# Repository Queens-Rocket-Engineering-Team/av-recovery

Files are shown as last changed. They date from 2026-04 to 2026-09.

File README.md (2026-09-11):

# Avionics Recovery (GPS and Altimter)
> 2023-2026 Season - Recovery Projects

> [!IMPORTANT]
> Make sure to initialize and pull the repository's git submodules to acquire all schematic library and board design dependencies:
> ```bash
> git submodule update --init --recursive
> ```

-  Repo contains board's **firmware**, **schematics**, and related **documentation and datasheets**.
-  The **Main** branch contains current functional hardware/software
-  **Branches** contain board revisions/versions or planned features/fixes.
-  If you're contributing, **make sure you're working in a branch other than Main**

### Folder Structure
- [`/Schematics`](./Schematics/) : PCB design files (KiCad V8)  
- [`/Firmware`](./Firmware/) : Arduino C/C++ code (for STM)
- [`/Datasheets`](./Datasheets/) : Datasheets and reference materials

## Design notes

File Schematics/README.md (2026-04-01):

# Schematics

This directory contains all schematics involved in this iteration of the Avionics Recovery system.

## GPS Module
- Acquires GPS signal
- Logs GPS data locally

## Altimter Module
- Tracks altitude using pressure and accelerometer
- Deploys parachute charges
- Logs altitude, pressure, events, etc. locally

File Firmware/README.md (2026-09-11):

# Recovery Module Firmware

This directory contains the firmware for the avionics Recovery Modules. The module firmware in this directory should be mostly functional.

We currently use the Arduino IDE with the STM32Duino core ("STM32 MCU based boards" by STMicroelectronics, working with 2.7.1) for developing firmware for our modules. We flash firmware to the modules using SWD via an STLinkV2.

## Attributions

Our firmware uses a variety of external libraries. Most libraries can be found through the Arduino library manager, and those that cannot have the corresponding GitHub link beside their include statements. We have taken care not to include any external libraries within our repository; only code we have written (or have modified and credited) are included here.

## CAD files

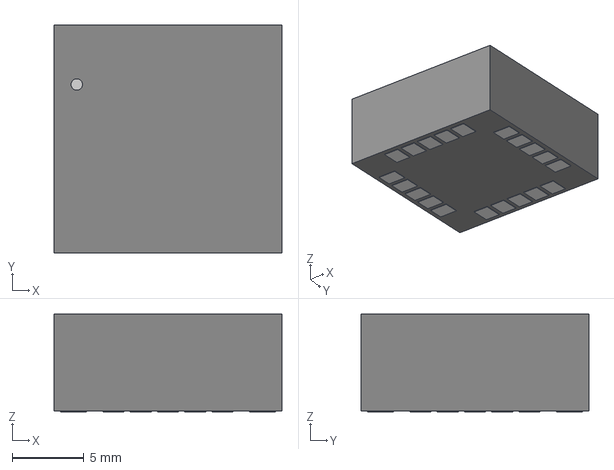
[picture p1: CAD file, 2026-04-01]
Schematics/GPS_Antenna_Board/models/SAM-M10Q_UBL.step
15.9 x 15.9 x 6.81 mm

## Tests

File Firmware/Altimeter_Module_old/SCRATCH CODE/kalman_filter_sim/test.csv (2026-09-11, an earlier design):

Time | Actual Altitude | Measured Altitude | Estimated Altitude | Actual Velocity | Estimated Velocity
0 | 0.0045 | -0.1955 | -0.101693 | 0.3 | 0.195812
0.01 | 0.012 | 0.212 | 0.0209463 | 0.6 | 0.614993
0.02 | 0.0225 | -0.1775 | -0.0386365 | 0.9 | 0.84776
0.03 | 0.036 | 0.136 | 0.0205453 | 1.2 | 1.19597
0.04 | 0.0525 | 0.4525 | 0.153328 | 1.5 | 1.61529
0.05 | 0.072 | -0.228 | 0.0600471 | 1.8 | 1.80436
0.06 | 0.0945 | -0.4055 | -0.0534859 | 2.1 | 1.97128
0.07 | 0.12 | -0.08 | -0.0452763 | 2.4 | 2.25728
0.08 | 0.1485 | -0.3515 | -0.110828 | 2.7 | 2.46666
0.09 | 0.18 | -0.12 | -0.0942345 | 3 | 2.7561
0.1 | 0.2145 | -0.1855 | -0.0977243 | 3.3 | 3.02255
0.11 | 0.252 | 0.452 | 0.074034 | 3.6 | 3.46258
0.12 | 0.2925 | -0.00750001 | 0.0783585 | 3.9 | 3.72979
0.13 | 0.336 | 0.036 | 0.0952273 | 4.2 | 4.00786
0.14 | 0.3825 | 0.5825 | 0.257225 | 4.5 | 4.42828
0.15 | 0.432 | 0.832 | 0.445922 | 4.8 | 4.8702
0.16 | 0.4845 | 0.1845 | 0.411931 | 5.1 | 5.08501
0.17 | 0.54 | 0.94 | 0.592801 | 5.4 | 5.51353
0.18 | 0.5985 | 0.3985 | 0.58164 | 5.7 | 5.74474
0.19 | 0.66 | 0.26 | 0.537766 | 6 | 5.94092
0.2 | 0.7245 | 1.1245 | 0.74073 | 6.3 | 6.38298
0.21 | 0.792 | 0.392 | 0.694199 | 6.6 | 6.57112
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

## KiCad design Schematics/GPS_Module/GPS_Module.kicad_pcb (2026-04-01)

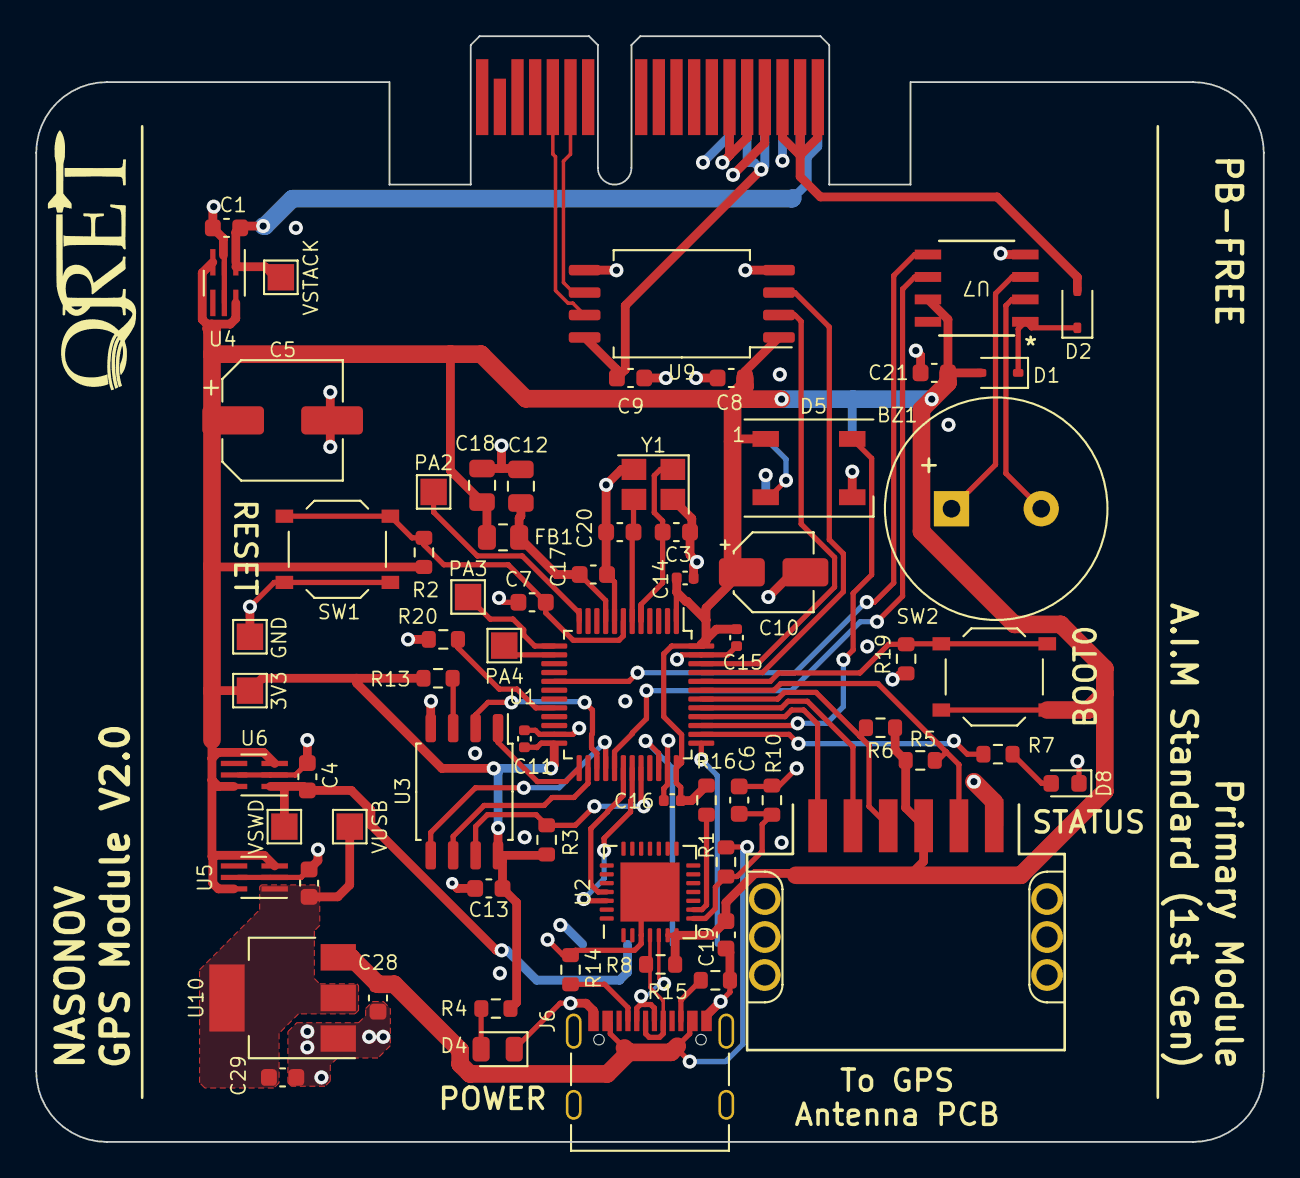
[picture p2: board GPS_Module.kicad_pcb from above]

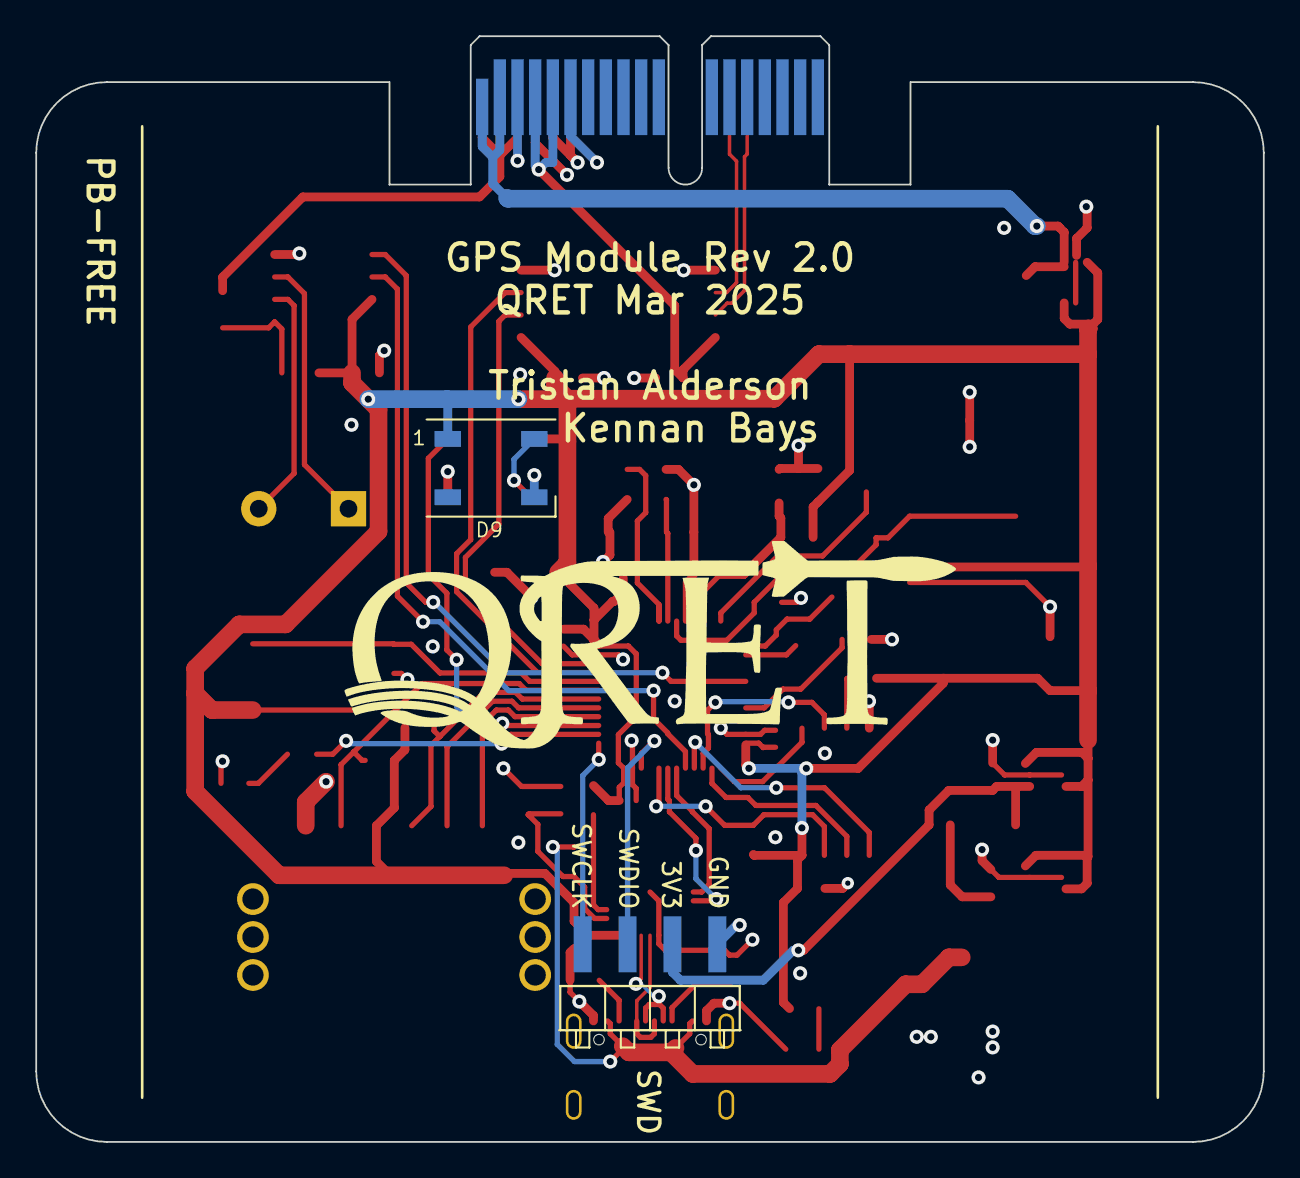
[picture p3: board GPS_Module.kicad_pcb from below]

Board: 4 copper layers, 69.5 x 62.6 mm, 70 parts (2 on the bottom side), 51 nets.

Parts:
BZ1: PS1240P02BT; Buzzer_12.6x9.5RM5.0
C1, C2, C4, C6: 1uF; C_0603_1608Metric
C3, C20: 10p; C_0603_1608Metric
C5: 100uF; CP_Elec_6.3x5.9
C7, C13, C21: 100nF; C_0603_1608Metric
C8, C9: 0.1u; C_0603_1608Metric
C10: 10uF; CP_Elec_4x5.4
C11, C14, C15, C16: 100n; C_0402_1005Metric
C12, C18: 1uF; C_0805_2012Metric
C17: 10n; C_0603_1608Metric
C19, C28, C29: 10uF; C_0603_1608Metric
D1, D2: 1N5819WS; D_SOD-323
D4: PWR_LED (GRN); LED_0805_2012Metric
D5, D9: WS2812B; LED_WS2812B_PLCC4_5.0x5.0mm_P3.2mm
D8: DB_LED (YLW); LED_0603_1608Metric
FB1: 100R; R_0805_2012Metric
J1: GT8E-6P-2H(55); CONN_GT8E-6P-2H(55)
J2: SWD_01x04_Pin; SWD_PinHeader_1x04_P2.54mm_Horizontal_SMD
J4: Stack Male Edge Connector; BUS_PCIexpress_x1
J6: USB_C_Female_USB2_Small; USB_C_DB-108PWB
R1: 22k; R_0603_1608Metric
R2, R3, R13: 10k; R_0603_1608Metric
R4: 3.3k; R_0603_1608Metric
R5, R6: 2.2k; R_0603_1608Metric
R7: 680; R_0603_1608Metric
R8: 1.5k; R_0603_1608Metric
R10: 47k; R_0603_1608Metric
R14, R15: 5.1k; R_0603_1608Metric
R16: 1k; R_0603_1608Metric
R19, R20: 100k; R_0603_1608Metric
SW1: SW_STM_RESET; SW_Push_1P1T_XKB_TS-1187A
SW2: SW_STM_BOOT_MODE; SW_Push_1P1T_XKB_TS-1187A
TP1: VSTACK; TestPoint_Pad_1.5x1.5mm
TP2: VUSB; TestPoint_Pad_1.5x1.5mm
TP3: VSWD; TestPoint_Pad_1.5x1.5mm
TP4: PA4; TestPoint_Pad_1.5x1.5mm
TP6: GND; TestPoint_Pad_1.5x1.5mm
TP7: 3V3; TestPoint_Pad_1.5x1.5mm
TP10: PA2; TestPoint_Pad_1.5x1.5mm
TP11: PA3; TestPoint_Pad_1.5x1.5mm
U1: STM32F103CBT6; LQFP-48_7x7mm_P0.5mm
U2: CP2102N-Axx-xQFN28; QFN-28-1EP_5x5mm_P0.5mm_EP3.35x3.35mm
U3: W25Q128JVS; SOIC-8_5.23x5.23mm_P1.27mm
U4, U5, U6: LM66100DCKR; SC-70-6_Handsoldering
U7: TPM8837C-SO1R; SOP-8_TPK
U9: ISO1042BQDWVR; SOIC-8 ISO1042BDWV
U10: AMS1117-3.3; SOT-223-3_TabPin2
Y1: X322516MMB4SI; Crystal_SMD_3225-4Pin_3.2x2.5mm

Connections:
5V_RAW: C28.1, J6.A4 (VBUS), J6.A9 (VBUS), J6.B4 (VBUS), J6.B9 (VBUS), R1.2, U10.3 (VI)
+3.3V: C5.1, C8.2, C10.1, C11.1, C13.1, C14.1, C15.1, C16.1, C18.1, C19.2, C21.1, D1.2 (A), D5.1 (VDD), D9.1 (VDD), FB1.2, J1.3, R2.2, R3.2, R4.2, R5.2, R6.1, R8.1, R13.2, R16.2, SW2.2, TP7.1, U1.1 (VBAT), U1.24 (VDD), U1.36 (VDD), U1.48 (VDD), U2.6 (VDD), U2.7 (VREGIN), U3.8 (VCC), U4.3 (*CE), U4.6 (VOUT), U5.3 (*CE), U5.6 (VOUT), U6.3 (*CE), U6.6 (VOUT), U7.7 (NSLEEP), U7.8 (VCC), U9.1 (VCC1)
+3.3VA: C12.1, C17.1, FB1.1, U1.9 (VDDA)
+5V: C9.2, J4.A4 (5.0V_A), J4.A5 (5.0V_A), U9.8 (VCC2)
+BATT: D2.2 (A), J4.B1 (BATT_A), J4.B2 (BATT_A), J4.B3 (BATT_A)
BOOT0: R19.2, SW2.1, U1.44 (BOOT0)
BOOT1: R20.2, U1.20 (PB2)
BUZZER_A: U1.29 (PA8), U7.6 (IN1)
BUZZER_B: U1.17 (PA7), U7.5 (IN2)
CAN_H: J4.B14 (CAN_H), U9.7 (CANH)
CAN_L: J4.B13 (CAN_L), U9.6 (CANL)
CAN_RX: U1.45 (PB8), U9.3 (RXD)
CAN_TX: U1.46 (PB9), U9.2 (TXD)
CS_FL: U1.25 (PB12), U3.1 (~CS)
DB_LED: R7.2, U1.38 (PA15)
EXTINT_GPS: J1.5, U1.41 (PB5)
GND: C1.2, C2.2, C3.2, C4.2, C5.2, C6.1, C7.2, C8.1, C9.1, C10.2, C11.2, C12.2, C13.2, C14.2, C15.2, C16.2, C17.2, C18.2, C19.1, C20.2, C21.2, C28.2, C29.2, D4.1 (K), D5.3 (VSS), D8.1 (K), D9.3 (VSS), J1.1, J2.1 (GND), J4.A3 (GND_A), J4.A6 (GND_A), J4.B4 (GND_A), J4.B5 (GND_A), J4.B6 (GND_A), J6.A1 (GND), J6.A12 (GND), J6.B1 (GND), J6.B12 (GND), R10.1, R14.2, R15.2, R19.1, R20.1, SW1.1, TP6.1, U1.8 (VSSA), U1.23 (VSS), U1.35 (VSS), U1.47 (VSS), U2.3 (GND), U2.29 (GND), U3.4 (GND), U4.2 (GND), U4.5 (ST), U5.2 (GND), U5.5 (ST), U6.2 (GND), U6.5 (ST), U7.4 (GND), U9.4 (GND1), U9.5 (GND2), U10.1 (GND), Y1.2, Y1.4
MISO_FL: U1.27 (PB14), U3.2 (DO(IO1))
MOSI_FL: U1.28 (PB15), U3.5 (DI(IO0))
unnamed: BZ1.2 (+), U7.2 (OUT1)
unnamed: BZ1.1 (-), U7.3 (OUT2)
unnamed: D1.1 (K), D2.1 (K), U7.1 (VM)
unnamed: D4.2 (A), R4.1
unnamed: D5.2 (DOUT), D9.4 (DIN)
unnamed: D8.2 (A), R7.1
unnamed: J6.A5 (CC1), R14.1
unnamed: J6.B5 (CC2), R15.1
unnamed: TP10.1, U1.12 (PA2)
unnamed: TP11.1, U1.13 (PA3)
unnamed: TP4.1, U1.14 (PA4)
unnamed: C6.2, R1.1, R10.2, U2.8 (VBUS)
unnamed: R16.1, U2.9 (~RST)
unnamed: R13.1, U3.3 (IO2)
OSC_IN: C3.1, U1.5 (PD0), Y1.1
OSC_OUT: C20.1, U1.6 (PD1), Y1.3
RESET_FL: R3.1, U1.32 (PA11), U3.7 (IO3)
RGB_DATA: D5.4 (DIN), U1.39 (PB3)
RST_GPS: J1.6, U1.40 (PB4)
SCK_FL: U1.26 (PB13), U3.6 (CLK)
SCL_GPS: J1.4, R6.2, U1.42 (PB6)
SDA_GPS: J1.2, R5.1, U1.43 (PB7)
STM_RESET: C7.1, R2.1, SW1.2, U1.7 (NRST)
SWCLK: J2.4 (SWCLK), U1.37 (PA14)
SWDIO: J2.3 (SWDIO), U1.34 (PA13)
USB_D+: J6.A6 (D+), J6.B6 (D+), R8.2, U2.4 (D+)
USB_D-: J6.A7 (D-), J6.B7 (D-), U2.5 (D-)
USB_RX: U1.31 (PA10), U2.26 (TXD)
USB_TX: U1.30 (PA9), U2.25 (RXD)
V_PSU: C1.1, J4.A1 (3.3V_A), J4.A2 (3.3V_A), TP1.1, U4.1 (VIN)
V_REGUSB: C2.1, C29.1, TP2.1, U5.1 (VIN), U10.2 (VO)
V_SWD: C4.1, J2.2 (3V3), TP3.1, U6.1 (VIN)

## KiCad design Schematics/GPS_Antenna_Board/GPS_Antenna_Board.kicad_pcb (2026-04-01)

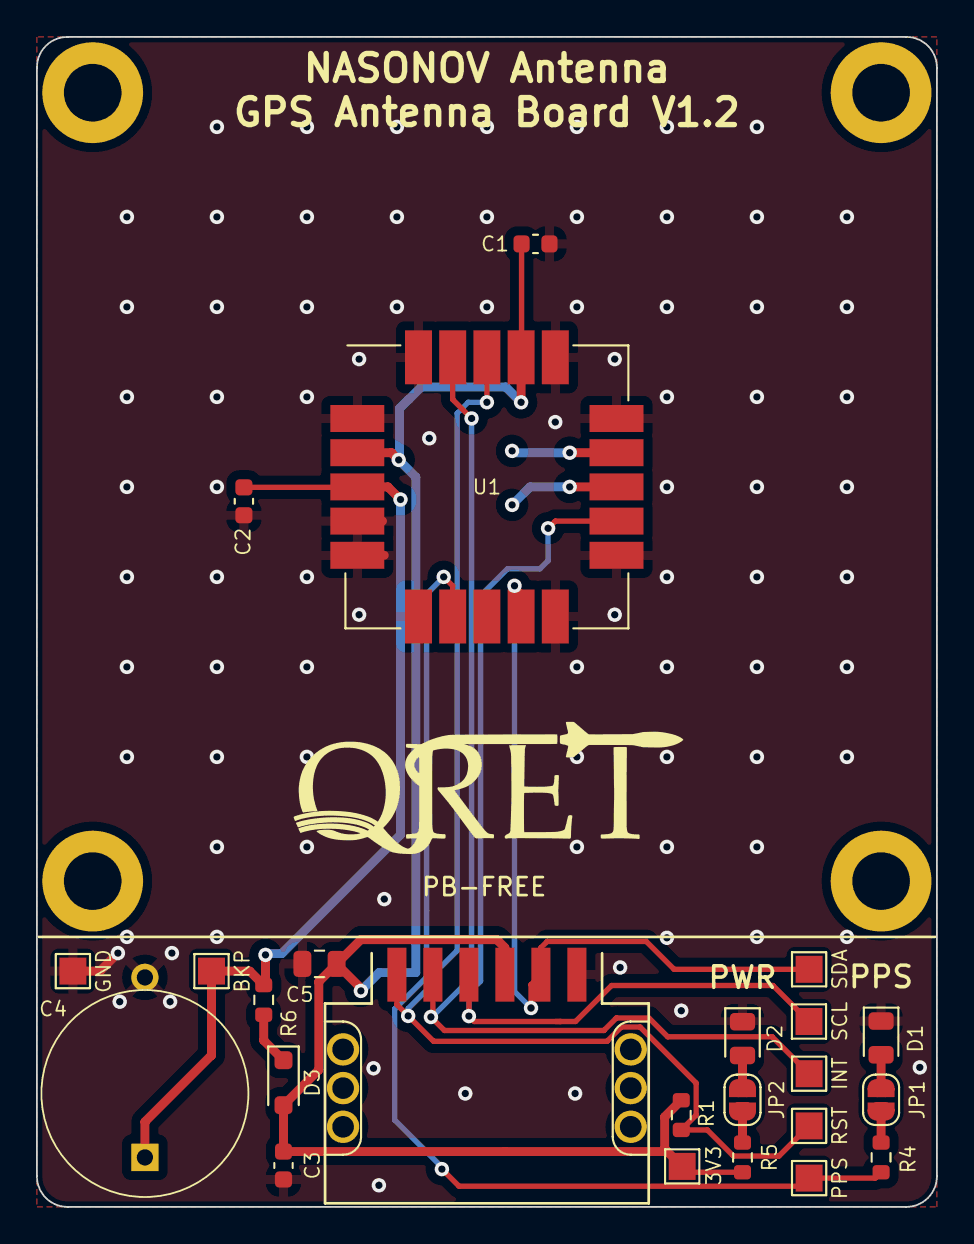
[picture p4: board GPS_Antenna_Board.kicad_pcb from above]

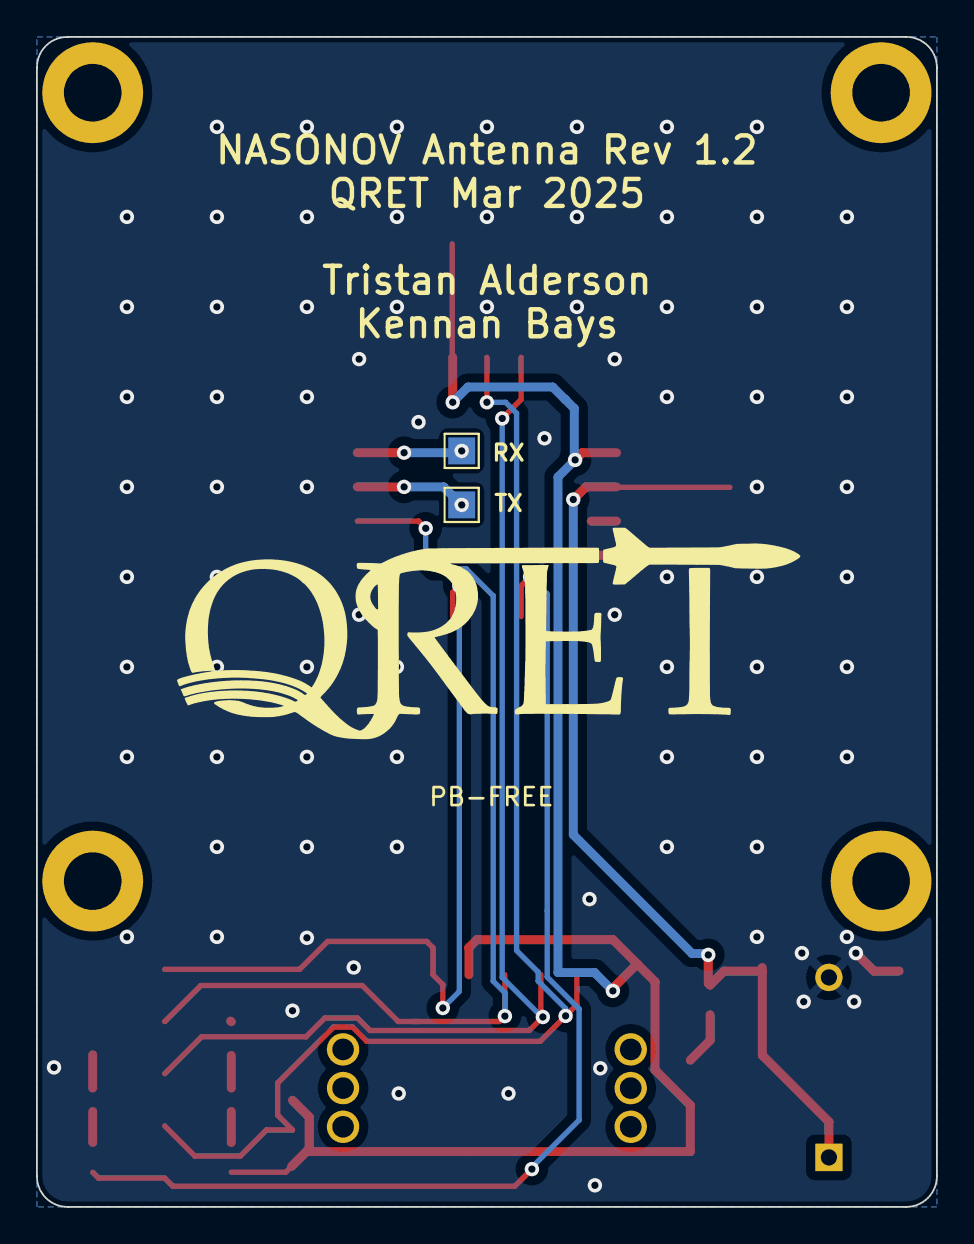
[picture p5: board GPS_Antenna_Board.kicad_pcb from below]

Board: 2 copper layers, 50.0 x 65.0 mm, 30 parts (2 on the bottom side), 15 nets.

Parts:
C1, C2: 100nF; C_0603_1608Metric
C3: 1uF; C_0603_1608Metric
C4: 330mF; CB5R5334HF-ZJP
C5: 47uF; C_0805_2012Metric
D1: White; LED_0805_2012Metric
D2: Green; LED_0805_2012Metric
D3: 1N5819WS; D_SOD-323_HandSoldering
H1, H2, H3, H4: MountingHole; MountingHole_3.2mm_M3_DIN965_Pad
J1: GT8E-6P-2H(55); CONN_GT8E-6P-2H(55)
JP1: ENA_PPS_LED; SolderJumper-2_P1.3mm_Open_RoundedPad1.0x1.5mm
JP2: ENA_PWR_LED; SolderJumper-2_P1.3mm_Open_RoundedPad1.0x1.5mm
R1: 10k; R_0603_1608Metric
R4: 2.2k; R_0603_1608Metric
R5: 3.3k; R_0603_1608Metric
R6: 100R; R_0603_1608Metric
TP1: GND; TestPoint_Pad_1.5x1.5mm
TP2: SCL; TestPoint_Pad_1.5x1.5mm
TP3: SDA; TestPoint_Pad_1.5x1.5mm
TP4: BKP; TestPoint_Pad_1.5x1.5mm
TP5: RST; TestPoint_Pad_1.5x1.5mm
TP6: INT; TestPoint_Pad_1.5x1.5mm
TP7: PPS; TestPoint_Pad_1.5x1.5mm
TP8: 3V3; TestPoint_Pad_1.5x1.5mm
TP9: RX; TestPoint_Pad_1.5x1.5mm
TP10: TX; TestPoint_Pad_1.5x1.5mm
U1: SAM-M10Q; ublox_SAM-M8Q_HandSolder

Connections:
+3.3V: C1.2, C3.1, C5.2, D3.2 (A), J1.3, R1.1, R5.1, TP8.1, U1.2 (VCC_IO), U1.17 (VCC)
BCKP_BATT: C2.2, C4.1, R6.2, TP4.1, U1.3 (V_BCKP)
GND: C1.1, C2.1, C3.2, C4.2, C5.1, D1.1 (K), D2.1 (K), J1.1, TP1.1, U1.1 (GND), U1.4 (GND), U1.5 (GND), U1.6 (GND), U1.10 (GND), U1.11 (GND), U1.15 (GND), U1.16 (GND), U1.20 (GND)
GPS_EXTINT: J1.5, TP6.1, U1.19 (EXTINT)
GPS_PPS: R4.1, TP7.1, U1.7 (TIMEPULSE)
GPS_RST: J1.6, R1.2, TP5.1, U1.18 (~RESET)
unnamed: D1.2 (A), JP1.1 (A)
unnamed: D2.2 (A), JP2.1 (A)
unnamed: D3.1 (K), R6.1
unnamed: JP1.2 (B), R4.2
unnamed: JP2.2 (B), R5.2
unnamed: TP9.1, U1.14 (RXD)
unnamed: TP10.1, U1.13 (TXD)
SCL: J1.4, TP2.1, U1.12 (SCL)
SDA: J1.2, TP3.1, U1.9 (SDA)

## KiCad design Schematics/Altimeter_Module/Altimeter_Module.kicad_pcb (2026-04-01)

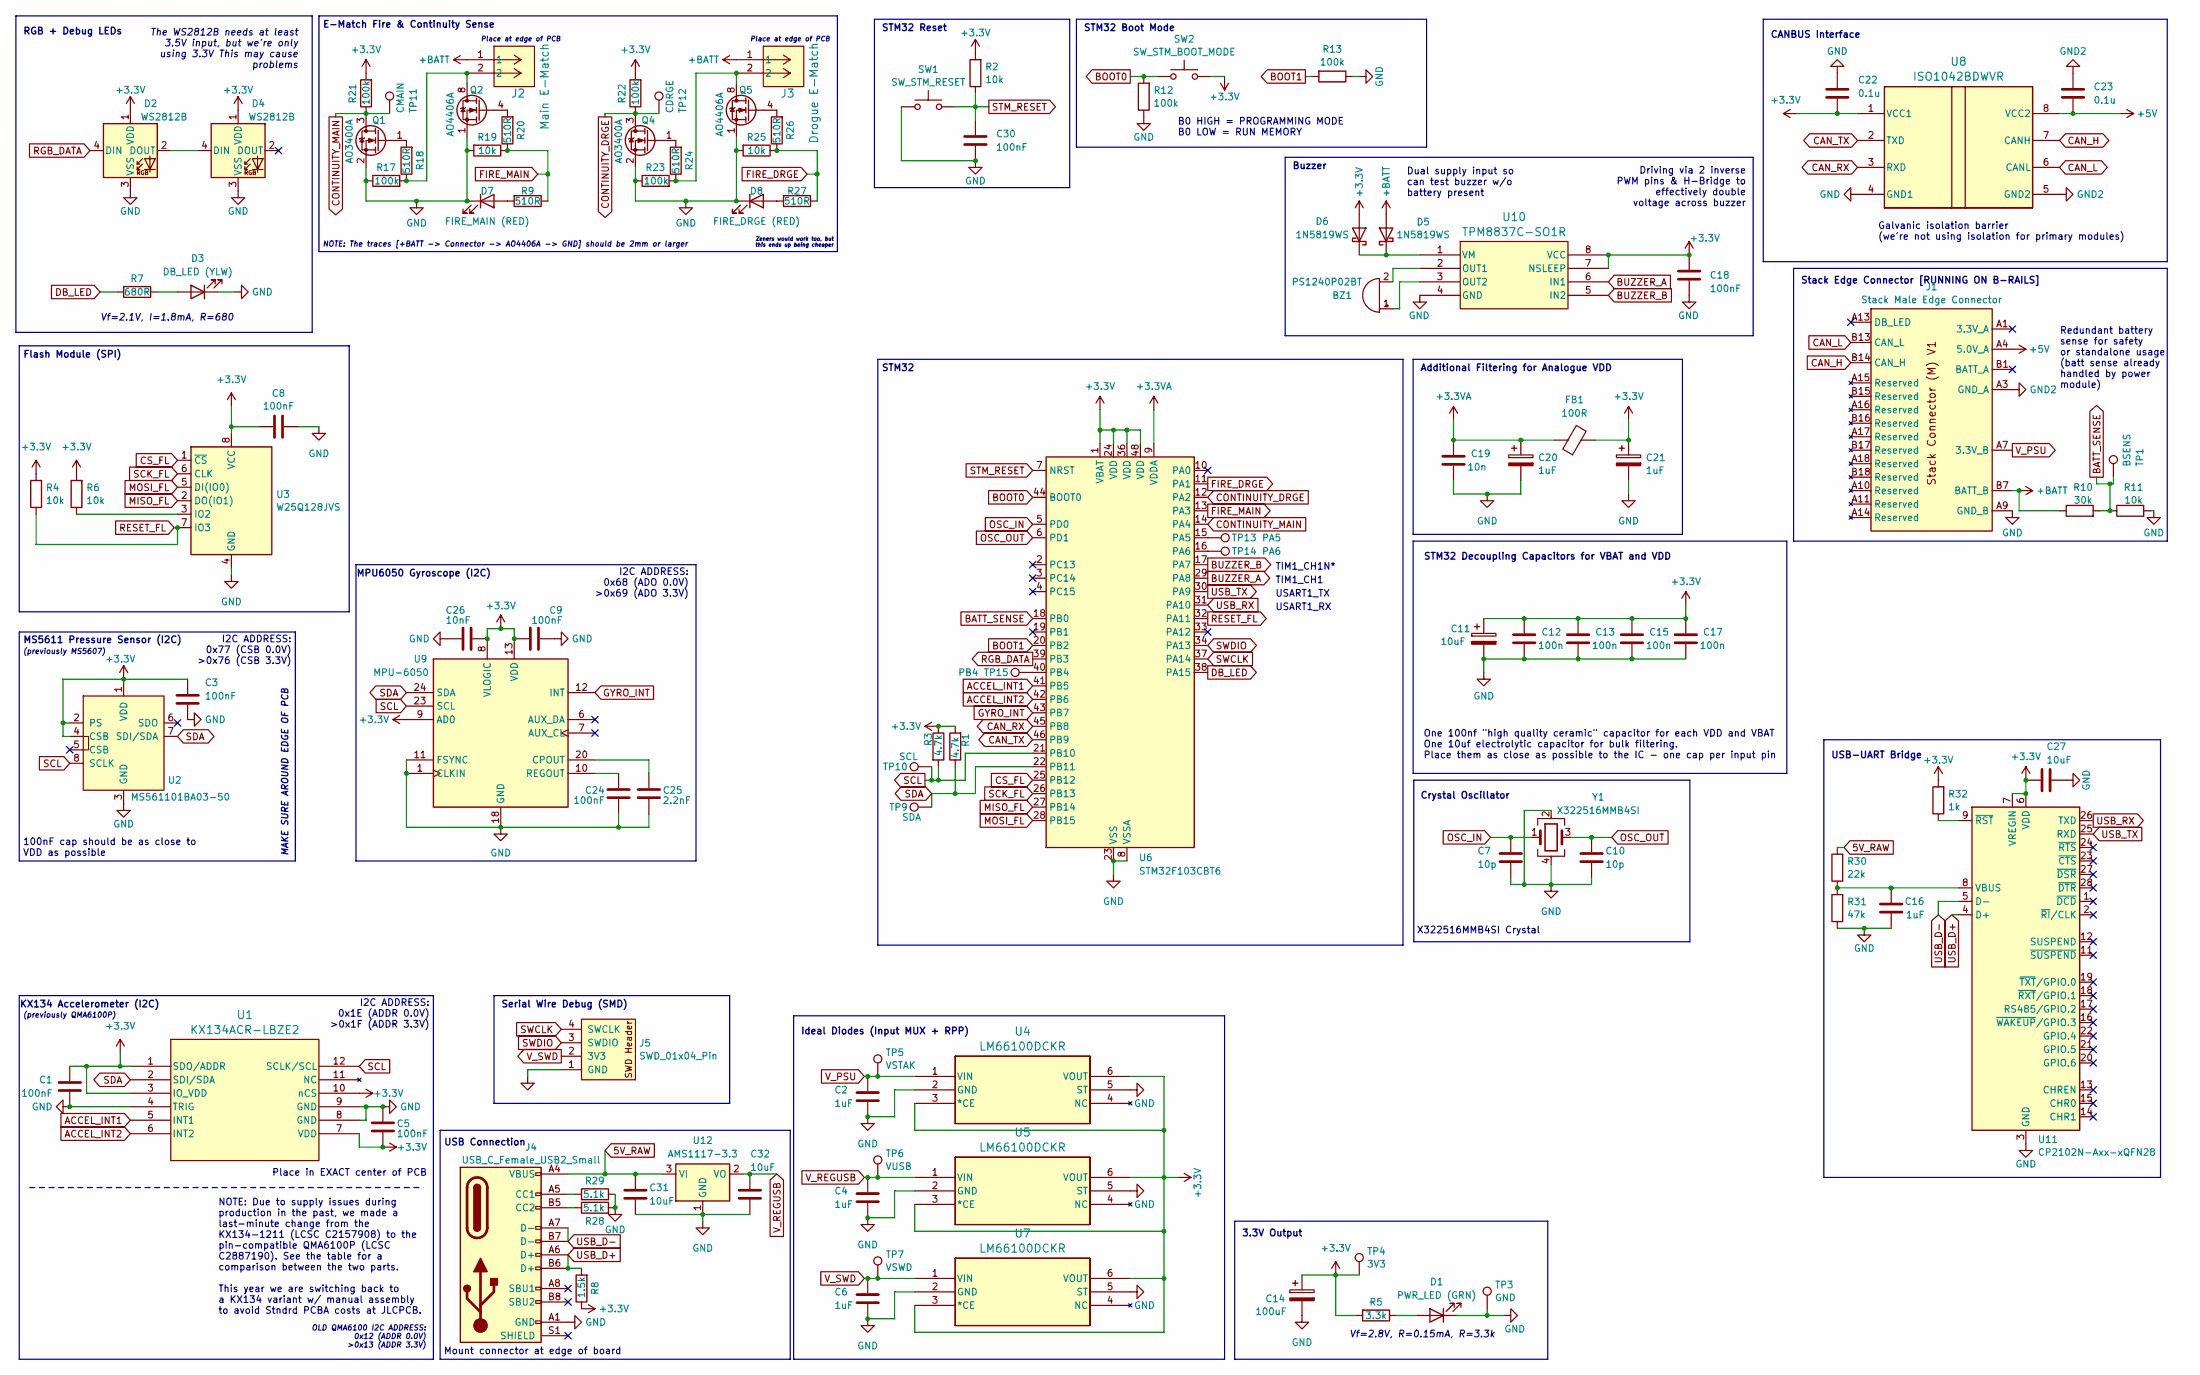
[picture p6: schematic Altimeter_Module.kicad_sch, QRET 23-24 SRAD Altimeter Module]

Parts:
BZ1: PS1240P02BT; Buzzer_12.6x9.5RM5.0; Digikey 445-2525-1-ND
C1, C3, C5, C8, C9, C18, C24, C30: 100nF; C_0603_1608Metric; JLCPCB C14663
C2, C4, C6, C16: 1uF; C_0603_1608Metric; JLCPCB C15849
C7, C10: 10p; C_0603_1608Metric; JLCPCB C1634
C11: 10uF; CP_Elec_4x5.4; Digikey 732-8411-1-ND
C12, C13, C15, C17: 100n; C_0402_1005Metric; JLCPCB C1525
C14: 100uF; CP_Elec_6.3x5.9; Digikey 732-8419-1-ND
C19: 10n; C_0603_1608Metric; JLCPCB C57112
C20, C21: 1uF; C_0805_2012Metric; JLCPCB C28323
C22, C23: 0.1u; C_0603_1608Metric; JLCPCB C14663
C25: 2.2nF; C_0603_1608Metric; JLCPCB C1604
C26: 10nF; C_0603_1608Metric; JLCPCB C57112
C27, C31, C32: 10uF; C_0603_1608Metric; JLCPCB C96446
D1: PWR_LED (GRN); LED_0805_2012Metric; JLCPCB C2297
D2, D4: WS2812B; LED_WS2812B_PLCC4_5.0x5.0mm_P3.2mm; Digikey 1568-COM-16347CT-ND
D3: DB_LED (YLW); LED_0603_1608Metric; JLCPCB C72038
D5, D6: 1N5819WS; D_SOD-323; JLCPCB C191023
D7: FIRE_MAIN (RED); LED_0603_1608Metric; JLCPCB C2286
D8: FIRE_DRGE (RED); LED_0603_1608Metric; JLCPCB C2286
FB1: 100R; R_0805_2012Metric; JLCPCB C1015
J1: Stack Male Edge Connector; BUS_PCIexpress_x1
J2: Main E-Match; CONN_2-1445057-2_TYCO; Digikey A33212CT-ND
J3: Drogue E-Match; CONN_2-1445057-2_TYCO; Digikey A33212CT-ND
J4: USB_C_Female_USB2_Small; USB_C_DB-108PWB; JLCPCB C5178541
J5: SWD_01x04_Pin; SWD_PinHeader_1x04_P2.54mm_Horizontal_SMD; Digikey 952-3233-ND
Q1, Q4: AO3400A; SOT-23; JLCPCB C20917
Q2, Q5: AO4406A; SOIC-8_3.9x4.9mm_P1.27mm; JLCPCB C5155213
R1, R3: 4.7k; R_0603_1608Metric; JLCPCB C23162
R2, R4, R6, R11, R19, R25: 10k; R_0603_1608Metric; JLCPCB C25804
R5: 3.3k; R_0603_1608Metric; JLCPCB C22978
R7: 680R; R_0603_1608Metric; JLCPCB C23228
R8: 1.5k; R_0603_1608Metric; JLCPCB C22843
R9, R18, R20, R24, R26, R27: 510R; R_0603_1608Metric; JLCPCB C23193
R10: 30k; R_0603_1608Metric; JLCPCB C22984
R12, R13, R17, R21, R22, R23: 100k; R_0603_1608Metric; JLCPCB C25803
R28, R29: 5.1k; R_0603_1608Metric; JLCPCB C23186
R30: 22k; R_0603_1608Metric; JLCPCB C31850
R31: 47k; R_0603_1608Metric; JLCPCB C25819
R32: 1k; R_0603_1608Metric; JLCPCB C21190
SW1: SW_STM_RESET; SW_Push_1P1T_XKB_TS-1187A; JLCPCB C318884
SW2: SW_STM_BOOT_MODE; SW_Push_1P1T_XKB_TS-1187A; JLCPCB C318884
TP1: BSENS; TestPoint_Pad_1.5x1.5mm
TP3: GND; TestPoint_Pad_1.5x1.5mm
TP4: 3V3; TestPoint_Pad_1.5x1.5mm
TP5: VSTAK; TestPoint_Pad_1.5x1.5mm
TP6: VUSB; TestPoint_Pad_1.5x1.5mm
TP7: VSWD; TestPoint_Pad_1.5x1.5mm
TP9: SDA; TestPoint_Pad_1.5x1.5mm
TP10: SCL; TestPoint_Pad_1.5x1.5mm
TP11: CMAIN; TestPoint_Pad_1.5x1.5mm
TP12: CDRGE; TestPoint_Pad_1.5x1.5mm
TP13: PA5; TestPoint_Pad_1.5x1.5mm
TP14: PA6; TestPoint_Pad_1.5x1.5mm
TP15: PB4; TestPoint_Pad_1.5x1.5mm
U1: KX134ACR-LBZE2; LGA-12_2x2mm_P0.5mm; Digikey 846-KX134ACR-LBZE2CT-ND
U2: MS561101BA03-50; MS5607_Handsolder; Digikey 223-1622-1-ND
U3: W25Q128JVS; SOIC-8_5.23x5.23mm_P1.27mm; JLCPCB C97521
U4, U5, U7: LM66100DCKR; SC-70-6_Handsoldering; JLCPCB C2869734
U6: STM32F103CBT6; LQFP-48_7x7mm_P0.5mm; JLCPCB C8304
U8: ISO1042BDWVR; SOIC-8 ISO1042BDWV; JLCPCB C484409
U9: MPU-6050; InvenSense_QFN-24_4x4mm_P0.5mm; JLCPCB C24112
U10: TPM8837C-SO1R; SOP-8_TPK; Digikey 5503-TPM8837C-SO1RCT-ND
U11: CP2102N-Axx-xQFN28; QFN-28-1EP_5x5mm_P0.5mm_EP3.35x3.35mm; JLCPCB C6568
U12: AMS1117-3.3; SOT-223-3_TabPin2; JLCPCB C6186
Y1: X322516MMB4SI; Crystal_SMD_3225-4Pin_3.2x2.5mm; JLCPCB C13738

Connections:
5V_RAW: C31.1, J4.A4 (VBUS), J4.A9 (VBUS), J4.B4 (VBUS), J4.B9 (VBUS), R30.2, U12.3 (VI)
+3.3V: C1.1, C3.1, C5.2, C8.1, C9.1, C11.1, C12.1, C13.1, C14.1, C15.1, C17.1, C18.1, C21.1, C22.2, C26.1, C27.2, D2.1 (VDD), D4.1 (VDD), D6.2 (A), FB1.2, R1.2, R2.2, R3.1, R4.2, R5.2, R6.2, R8.1, R21.2, R22.2, R32.2, SW2.2, TP4.1, U1.1 (SDO/ADDR), U1.3 (IO_VDD), U1.7 (VDD), U1.10 (nCS), U2.1 (VDD), U2.2 (PS), U2.4 (CSB), U3.8 (VCC), U4.3 (*CE), U4.6 (VOUT), U5.3 (*CE), U5.6 (VOUT), U6.1 (VBAT), U6.24 (VDD), U6.36 (VDD), U6.48 (VDD), U7.3 (*CE), U7.6 (VOUT), U8.1 (VCC1), U9.8 (VLOGIC), U9.9 (AD0), U9.13 (VDD), U10.7 (NSLEEP), U10.8 (VCC), U11.6 (VDD), U11.7 (VREGIN)
+3.3VA: C19.1, C20.1, FB1.1, U6.9 (VDDA)
+5V: C23.2, J1.A4 (5.0V_A), J1.A5 (5.0V_A), U8.8 (VCC2)
+BATT: D5.2 (A), J1.B7 (BATT_B), J1.B8 (BATT_B), J1.B9 (BATT_B), J2.1, J3.1, R10.1
ACCEL_INT1: U1.5 (INT1), U6.41 (PB5)
ACCEL_INT2: U1.6 (INT2), U6.42 (PB6)
BATT_SENSE: R10.2, R11.1, TP1.1, U6.18 (PB0)
BOOT0: R12.2, SW2.1, U6.44 (BOOT0)
BOOT1: R13.2, U6.20 (PB2)
BUZZER_A: U6.29 (PA8), U10.6 (IN1)
BUZZER_B: U6.17 (PA7), U10.5 (IN2)
CAN_H: J1.B14 (CAN_H), U8.7 (CANH)
CAN_L: J1.B13 (CAN_L), U8.6 (CANL)
CAN_RX: U6.45 (PB8), U8.3 (RXD)
CAN_TX: U6.46 (PB9), U8.2 (TXD)
CONTINUITY_DRGE: Q4.3 (D), R22.1, TP12.1, U6.12 (PA2)
CONTINUITY_MAIN: Q1.3 (D), R21.1, TP11.1, U6.14 (PA4)
CS_FL: U3.1 (~CS), U6.25 (PB12)
DB_LED: R7.2, U6.38 (PA15)
FIRE_DRGE: R25.1, R26.1, R27.1, U6.11 (PA1)
FIRE_MAIN: R9.1, R19.1, R20.1, U6.13 (PA3)
GND: C1.2, C2.2, C3.2, C4.2, C5.1, C6.2, C7.2, C8.2, C9.2, C10.2, C11.2, C12.2, C13.2, C14.2, C15.2, C16.1, C17.2, C18.2, C19.2, C20.2, C21.2, C22.1, C24.2, C25.2, C26.2, C27.1, C30.2, C31.2, C32.2, D1.1 (K), D2.3 (VSS), D3.1 (K), D4.3 (VSS), D7.1 (K), D8.1 (K), J1.A9 (GND_B), J1.A12 (GND_B), J1.B10 (GND_B), J1.B11 (GND_B), J1.B12 (GND_B), J4.A1 (GND), J4.A12 (GND), J4.B1 (GND), J4.B12 (GND), J5.1 (GND), Q1.2 (S), Q2.1 (S), Q2.2 (S), Q2.3 (S), Q4.2 (S), Q5.1 (S), Q5.2 (S), Q5.3 (S), R11.2, R12.1, R13.1, R17.1, R19.2, R23.1, R25.2, R28.2, R29.2, R31.1, SW1.1, TP3.1, U1.4 (TRIG), U1.8 (GND), U1.9 (GND), U2.3 (GND), U3.4 (GND), U4.2 (GND), U4.5 (ST), U5.2 (GND), U5.5 (ST), U6.8 (VSSA), U6.23 (VSS), U6.35 (VSS), U6.47 (VSS), U7.2 (GND), U7.5 (ST), U8.4 (GND1), U9.1 (CLKIN), U9.11 (FSYNC), U9.18 (GND), U10.4 (GND), U11.3 (GND), U11.29 (GND), U12.1 (GND), Y1.2, Y1.4
GND2: C23.1, J1.A3 (GND_A), J1.A6 (GND_A), J1.B4 (GND_A), J1.B5 (GND_A), J1.B6 (GND_A), U8.5 (GND2)
GYRO_INT: U6.43 (PB7), U9.12 (INT)
MISO_FL: U3.2 (DO(IO1)), U6.27 (PB14)
MOSI_FL: U3.5 (DI(IO0)), U6.28 (PB15)
unnamed: BZ1.2 (+), U10.2 (OUT1)
unnamed: BZ1.1 (-), U10.3 (OUT2)
unnamed: D1.2 (A), R5.1
unnamed: D2.2 (DOUT), D4.4 (DIN)
unnamed: D3.2 (A), R7.1
unnamed: D5.1 (K), D6.1 (K), U10.1 (VM)
unnamed: D7.2 (A), R9.2
unnamed: D8.2 (A), R27.2
unnamed: J2.2, Q2.5 (D), Q2.6 (D), Q2.7 (D), Q2.8 (D), R17.2, R18.1
unnamed: J3.2, Q5.5 (D), Q5.6 (D), Q5.7 (D), Q5.8 (D), R23.2, R24.1
unnamed: J4.A5 (CC1), R29.1
unnamed: J4.B5 (CC2), R28.1
unnamed: Q1.1 (G), R18.2
unnamed: Q2.4 (G), R20.2
unnamed: Q4.1 (G), R24.2
unnamed: Q5.4 (G), R26.2
unnamed: R6.1, U3.3 (IO2)
unnamed: TP13.1, U6.15 (PA5)
unnamed: TP14.1, U6.16 (PA6)
unnamed: TP15.1, U6.40 (PB4)
unnamed: C25.1, U9.20 (CPOUT)
unnamed: C24.1, U9.10 (REGOUT)
unnamed: C16.2, R30.1, R31.2, U11.8 (VBUS)
unnamed: R32.1, U11.9 (~RST)
OSC_IN: C7.1, U6.5 (PD0), Y1.1
OSC_OUT: C10.1, U6.6 (PD1), Y1.3
RESET_FL: R4.1, U3.7 (IO3), U6.32 (PA11)
RGB_DATA: D2.4 (DIN), U6.39 (PB3)
SCK_FL: U3.6 (CLK), U6.26 (PB13)
SCL: R3.2, TP10.1, U1.12 (SCLK/SCL), U2.8 (SCLK), U6.21 (PB10), U9.23 (SCL)
SDA: R1.1, TP9.1, U1.2 (SDI/SDA), U2.7 (SDI/SDA), U6.22 (PB11), U9.24 (SDA)
STM_RESET: C30.1, R2.1, SW1.2, U6.7 (NRST)
SWCLK: J5.4 (SWCLK), U6.37 (PA14)
SWDIO: J5.3 (SWDIO), U6.34 (PA13)
USB_D+: J4.A6 (D+), J4.B6 (D+), R8.2, U11.4 (D+)
USB_D-: J4.A7 (D-), J4.B7 (D-), U11.5 (D-)
USB_RX: U6.31 (PA10), U11.26 (TXD)
USB_TX: U6.30 (PA9), U11.25 (RXD)
V_PSU: C2.1, J1.A7 (3.3V_B), J1.A8 (3.3V_B), TP5.1, U4.1 (VIN)
V_REGUSB: C4.1, C32.1, TP6.1, U5.1 (VIN), U12.2 (VO)
V_SWD: C6.1, J5.2 (3V3), TP7.1, U7.1 (VIN)

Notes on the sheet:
Serial Wire Debug (SMD)
Flash Module (SPI)
RGB + Debug LEDs
The WS2812B needs at least 3.5V input, but we're only using 3.3V This may cause problems
Additional Filtering for Analogue VDD
(previously QMA6100P)
Stack Edge Connector [RUNNING ON B-RAILS]
NOTE: Due to supply issues during production in the past, we made a last-minute change from the KX134-1211 (LCSC C2157908) to the pin-compatible QMA6100P (LCSC C2887190). See the table for a comparison between the two parts. This year we are switching back to a KX134 variant w/ manual assembly to a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
Buzzer
Place at edge of PCB
Ideal Diodes (Input MUX + RPP)
Crystal Oscillator
Vf=2.1V, I=1.8mA, R=680
STM32
I2C ADDRESS: 0x1E (ADDR 0.0V) >0x1F (ADDR 3.3V)
B0 HIGH = PROGRAMMING MODE B0 LOW = RUN MEMORY
USART1_TX
USART1_RX
MS5611 Pressure Sensor (I2C)
Place in EXACT center of PCB
3.3V Output
OLD QMA6100 I2C ADDRESS: 0x12 (ADDR 0.0V) >0x13 (ADDR 3.3V)
Mount connector at edge of board
(previously MS5607)
X322516MMB4SI Crystal
CANBUS Interface
STM32 Decoupling Capacitors for VBAT and VDD
I2C ADDRESS: 0x68 (ADO 0.0V) >0x69 (ADO 3.3V)
STM32 Boot Mode
TIM1_CH1N*
TIM1_CH1
KX134 Accelerometer (I2C)
E-Match Fire & Continuity Sense
Galvanic isolation barrier (we're not using isolation for primary modules)
One 100nf "high quality ceramic" capacitor for each VDD and VBAT One 10uf electrolytic capacitor for bulk filtering. Place them as close as possible to the IC - one cap per input pin
NOTE: The traces [+BATT -> Connector -> AO4406A -> GND] should be 2mm or larger
Zeners would work too, but this ends up being cheaper
MAKE SURE AROUND EDGE OF PCB
Driving via 2 inverse PWM pins & H-Bridge to effectively double voltage across buzzer
100nF cap should be as close to VDD as possible

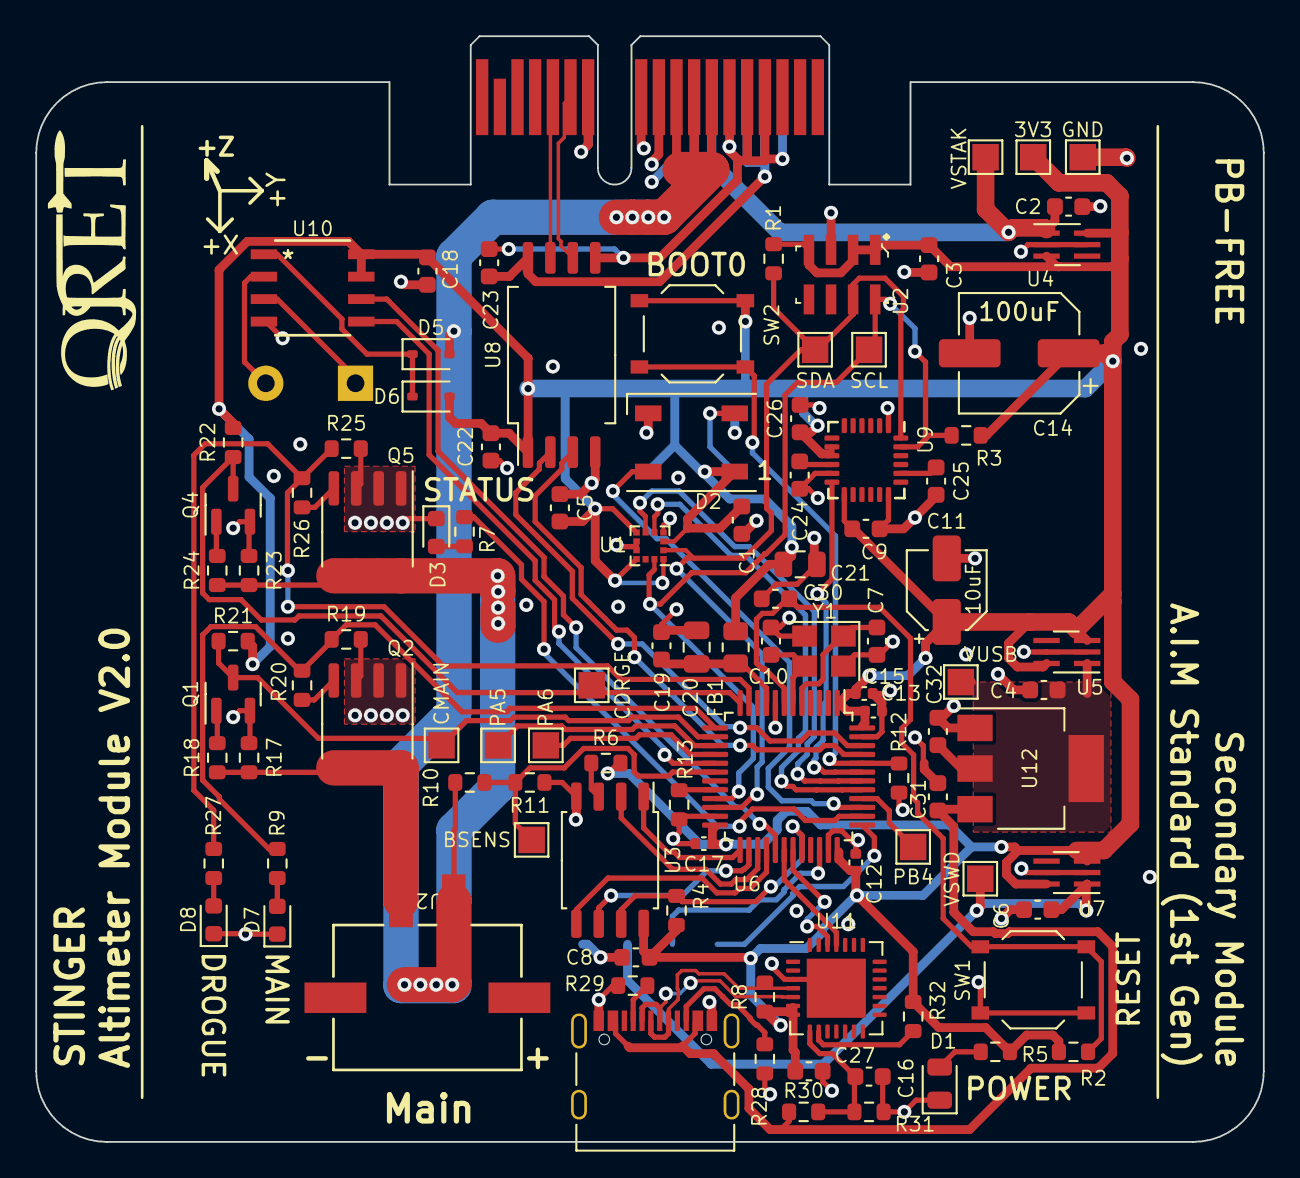
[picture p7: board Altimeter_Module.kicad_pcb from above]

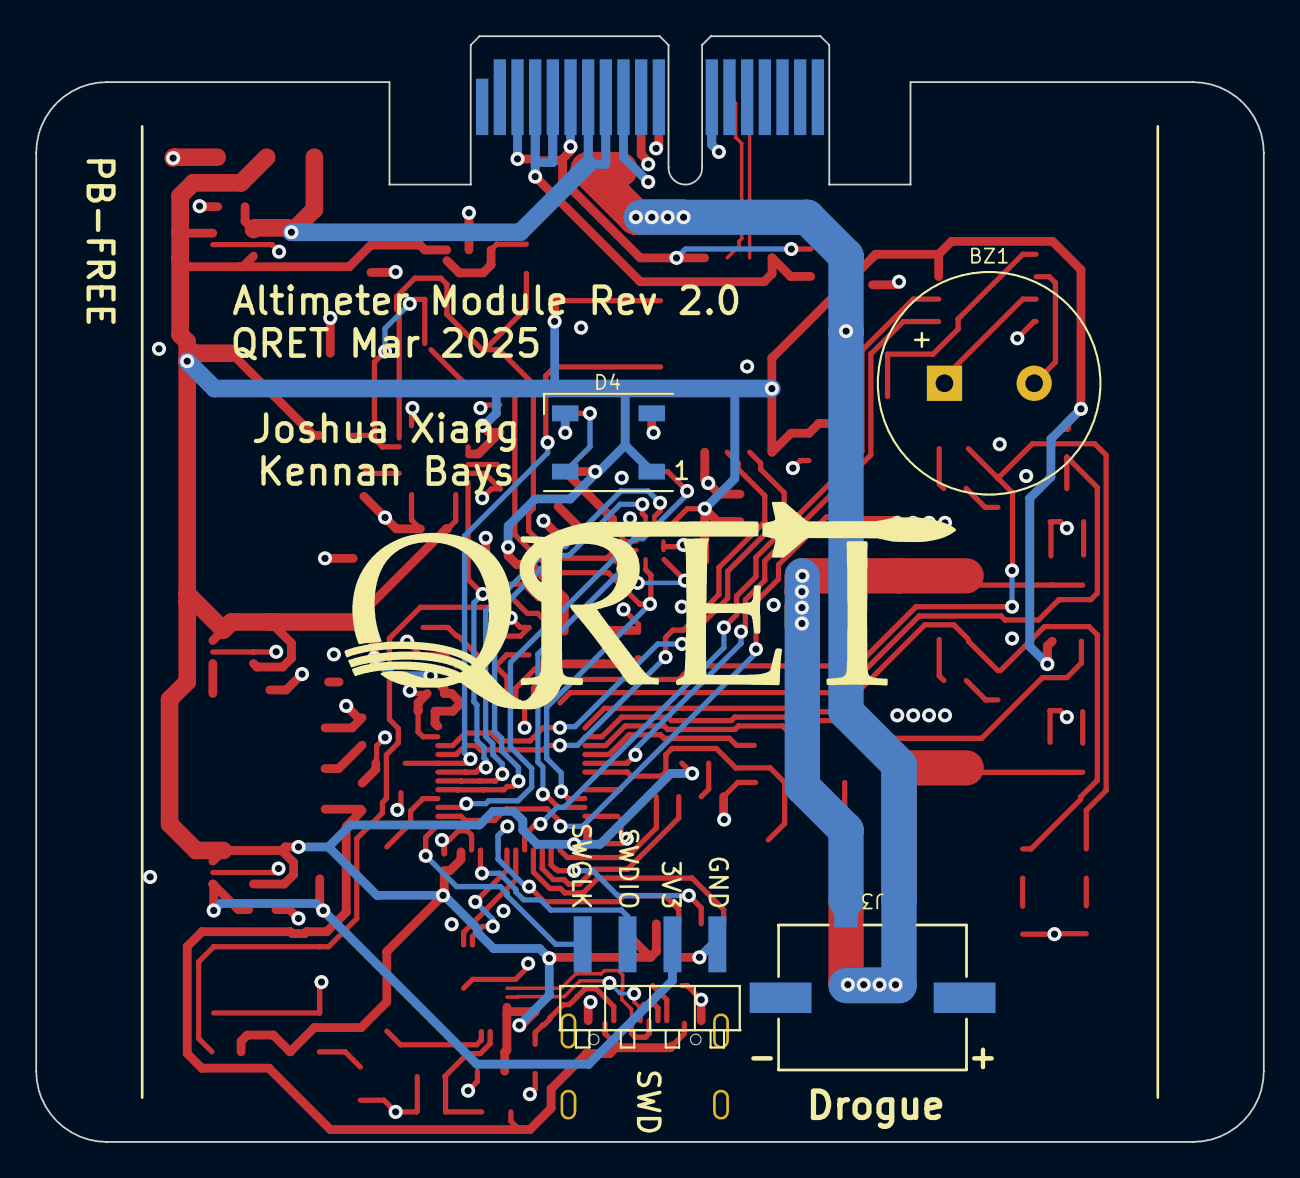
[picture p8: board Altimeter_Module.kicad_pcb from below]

Board: 4 copper layers, 69.5 x 62.6 mm, 106 parts (4 on the bottom side), 68 nets.

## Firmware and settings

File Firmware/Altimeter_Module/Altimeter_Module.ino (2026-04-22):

/*
QRET SRAD Avionics module - AIM
Authors: Brent Naumann, Tristan Alderson, Kennan Bays, Caelan Donovan, Ethan Toste, Andrew Gault
Env: Arduino 1.8.10, STM32duino 2.7.1
Updated: April.21.2026
Purpose: QRET SRAD Avionics module - AIM Altimeter Module Firmware V 2.0 (STINGER)

Sensors used:
 - ms5611 : Pressure and Temperature
 - mpu6050 : Gyroscope
 - kx134 : accelerometer 
*/

//Libraries to include
#include <Wire.h>
#include <SimpleKalmanFilter.h>
#include <Adafruit_MPU6050.h>
#include <SparkFun_KX13X.h> 
#include <SerialFlash.h>
#include <SPI.h>
#include "flashTable.h"
#include <tone.h>
#include <CANpackets.h>
#include "STM32_CAN.h" //IMPORTANT: DO NOT DOWNLOAD THE LATEST VERSION (DOWNLOAD 1.1.2)
#include "pinouts.h"
#include <HardwareSerial.h>
#include "MS5611.h" // https://github.com/RobTillaart/MS5611


#define BUZZER_TONE 1000
#define BUZZER_TONE_Q 500
const uint32_t BEEP_FREQ = 1000;

#define SERIAL_BAUD_RATE 115200
//#define SERIAL_BAUD_RATE 9600

//--- FILTER SETTINGS
#define M_UNCERT    15        //Uncertainty of taken measurements (varience)
#define EST_UNCERT  M_UNCERT  //Uncertainty of Kalman estimation (changes over time)
#define NOISE_SENS  0.008    //The filters sensitivity to unexpected changes. Range: 0.001 ->1
#define LAPSE_RATE -0.0065   //[K/m] change in temperature over height


//--- FLASH SETTINGS
uint16_t flashDelay = 250; // How frequently the debug LED should be toggled
uint32_t lastFlash = 0; // Last millis() the debug LED was toggle at

const uint8_t TABLE_NAME = 0;
const uint8_t TABLE_COLS = 11;
const uint32_t TABLE_SIZE = 16646144;
// IMPORTANT!!!; AT LEAST 2 BLOCK OF SPACE MUST BE RESERVED FOR FILE SYSTEM
// 16MiB = 16777216B, 2x 64KiB blocks = 131072B
// 16MiB - 128KiB = 16646144B

//--- CANBUS DATA SETTINGS
#define CANBUS_DATAINT 500 //[ms] interval bewteen each CANBUS message send.

//--- PREFLIGHT SETTINGS
#define PRE_DATAINT 35  //[ms] interval bewteen each log to FLASH.

//--- LAUNCH SETTINGS
#define LAUNCH_THRESHOLD  100  // [m]. Altitude difference from baseline to current threshold to declare launch. Must be greater than this for three cycles.
#define LAUNCH_GRACE      75 // [ms] Time for measurements to be above threshold before Launch declared

//--- ASCENT SETTINGS
#define ASC_DATAINT 20 //  [ms] interval bewteen each log to FLASH.
#define APO_GRACE   500 // [ms] Time for measurements to be above threshold before Apogee is declared

//--- DESCENT SETTINGS
#define DROGUE_DATAINT 20 //  [ms] interval between each log to FLASH.
#define MAIN_DATAINTFAST 500 // [ms] interval between each log to FLASH - slowed rate before 5000 ms
#define MAIN_DATAINTSLOW 1000 // [ms] interval between each log to FLASH - slowed rate after 5000 ms
#define LAND_THRESHOLD -0.5//[m/s] Velocity Threshold to declare land
#define LAND_GRACE  2000 // [ms] Time for measurements to be above threshold before Landing is declared
const uint16_t MAIN_DEPLOY_THRESHOLD = 1500/3.281;

//--- LAND SETTINGS
#define LAND_DATAINT 1000  //[ms] interval between each log to FLASH.
#define LAND_SLOW_DATAINT 2000 //[ms] interval between each log to FLASH.

// Global objects to declare
HardwareSerial usb(USB_RX_PIN, USB_TX_PIN);
//#define usb Serial              //For debugging when not using CANBUS

SimpleKalmanFilter kalmanFilter(M_UNCERT,EST_UNCERT,NOISE_SENS); 
MS5611 ms5611(MS5611_ADDR, &Wire);
Adafruit_MPU6050 mpu6050;
SparkFun_KX134 kxAccel;

FlashTable flash = FlashTable(TABLE_COLS, 16384, TABLE_SIZE, TABLE_NAME, 256);

STM32_CAN canb( CAN1, ALT );    //CAN1 ALT is PB8+PB9
static CAN_message_t CAN_TX_msg ;

//--- Global Variables
//sensors

outputData kxData;          //For kx134
sensors_event_t a, g, temp;  // for mpu6050

float Po;
float To;

float strike; // If strike >= 3 launch is detected.

//state machine
uint8_t STATE = 0;  //State flag for state machine


//Pre-Launch
unsigned long potentialLaunchStart; //saves time of possible launch start
bool potentialLaunch = 0;

//Ascent

unsigned long potentialApoStart;
bool potentialApo = 0;

//decent
unsigned long potentialLandStart;
bool potentialLand = 0;

//ascent-decent shared
float vel;  //Decent velocity
float prev_alt;  //velocity from previous measurement
unsigned long curTime;
unsigned long prevTime;

//data logging and CANBUS
unsigned long lastLog; // Time of last data log
unsigned long lastSend; // Time of last CANBUS send

//extra timers
int mainTimer = 0;
int landingTimer =0;

// ---   ---   ---   ---   ---   ---   ---   ---   ---   ---   ---   ---   ---   ---   ---   ---   ---   ---   ---

//      SETUP

// ---   ---   ---   ---   ---   ---   ---   ---   ---   ---   ---   ---   ---   ---   ---   ---   ---   ---   ---

void setup(){

  // Configure pinmodes
  pinMode(BUZZER_A_PIN, OUTPUT);
  pinMode(BUZZER_B_PIN, OUTPUT);
  pinMode(STATUS_LED_PIN, OUTPUT);
  pinMode(FIRE_MAIN_PIN,OUTPUT);
  pinMode(FIRE_DROGUE_PIN,OUTPUT);
  

  // Configure SPI
  SPI.setSCLK(PB13);
  SPI.setMISO(PB14);
  SPI.setMOSI(PB15);

  //Configure I2C PINS
  Wire.setSDA(SDA_PIN);
  Wire.setSCL(SCL_PIN);
  Wire.begin();

  //Start CANBUS
  canb.begin(); //automatic retransmission can be done using arg "true"
  canb.setBaudRate(500000); //500kbps

  //Start Serial
  usb.begin(SERIAL_BAUD_RATE);
  delay(1000);

  usb.print("BUZZER REACHED");      

  initBuzzer();
  setBuzzerFreq(BEEP_FREQ);

  // // STARTUP BEEP
  startBuzzer();
  delay(1000);
  stopBuzzer();
    
  digitalWrite(STATUS_LED_PIN,LOW);

  usb.println("Connecting to required devices...");
            
  /*------------------*\
  |    FLASH SETUP    |
  \*------------------*/
  usb.print("SEARCHING: SPI Flash chip");
  while (!SerialFlash.begin(FLASH_CS_PIN)) {
    delay(250);
  }//while
  usb.println("  - CONNECTED");
  
  while (SerialFlash.ready() == false) {}  

  // Initialize FlashTable object
  flash.init(&SerialFlash, &usb);

  // Note done loading
  for (int i=0; i<3; i++) {
    startBuzzer();
    delay(100);
    stopBuzzer();
    delay(100);
  }


  /*------------------*\
  |    MS5611 SETUP    |
  \*------------------*/
  usb.print("SEARCHING: MS5611");      
  while (!ms5611.begin()) {
    delay(10);
  }
  usb.println("  - CONNECTED"); //MS5611 connected

  // Set oversampling
  ms5611.setOversampling(OSR_ULTRA_LOW);

  /*-------------------*\
  |    MPU6050 SETUP    |
  \*-------------------*/  
    usb.print("SEARCHING: MPU6050");

    while(!mpu6050.begin(MPU6050_ADDR)) {
      delay(10);
    }//while()
    usb.println("  - CONNECTED");    //ms6050 connected

    mpu6050.setAccelerometerRange(MPU6050_RANGE_16_G); 
    mpu6050.setGyroRange(MPU6050_RANGE_500_DEG);
    mpu6050.setFilterBandwidth(MPU6050_BAND_21_HZ);

/*--------------------*\
|    KX134 SETUP       |
\*--------------------*/

usb.print("SEARCHING: KX134");

// Optional: slow down I2C for reliability
Wire.setClock(100000);

bool kx_detected = false;
byte kx_address = 0x1F;   // Default address for KX134

// Try initializing with SparkFun lib
if (kxAccel.begin(Wire, kx_address)) {
    kx_detected = true;
    usb.print("KX134 connected at 0x");
    usb.println(kx_address, HEX);
} else {
    // If init fails, read WHO_AM_I directly
    usb.println("KX134 begin() failed, checking WHO_AM_I...");

    Wire.beginTransmission(kx_address);
    Wire.write(0x13); // WHO_AM_I register
    Wire.endTransmission(false); // repeated start
    Wire.requestFrom(kx_address, (uint8_t)1);

    if (Wire.available()) {
        uint8_t whoAmI = Wire.read();
        usb.print("WHO_AM_I returned 0x");
        usb.println(whoAmI, HEX);

        if (whoAmI == 0x46) {
            usb.println("WHO_AM_I matches KX134 (0x46) — device is alive.");
            kx_detected = true;
        } else {
            usb.println("Unexpected WHO_AM_I value! Check wiring or library support.");
        }
    } else {
        usb.println("No response from device at 0x1F.");
    }
}

// If detected, configure the sensor manually
if (kx_detected) {
    // Software reset
    kxAccel.softwareReset();
    delay(50);

    // Set accelerometer range
    kxAccel.setRange(SFE_KX134_RANGE32G);
    kxAccel.enableAccel();

    usb.println("KX134 configured.");
} else {
    usb.println("KX134 setup failed.");
}


  // Get base measurements
  usb.println("Aquiring base Pressure...");
  Po = altimeterBasePres(500);
  usb.print("Base Pressure: ");
  usb.println(Po);
  
  usb.println("Aquiring base Temperature...");
  To = altimeterBaseTemp(500);
  usb.print("Base Temperature: ");
  usb.println(To);   
  
  usb.println("");
  usb.println("All sensors set up and configured.");
  usb.println("");

  // Startup delay - Check to enter debug mode
  usb.println("[MDE] SEND SERIAL TO ENTER DEBUG");
  uint32_t startTime = millis();
  while (!usb.available() and millis()-startTime < 4000) {}
  
  if (usb.available()) {
    byte d = usb.read();
    emptySerialBuffer();
    usb.println("[MDE] Entered Debug Mode");
    debugMode();
    while (true) {}
  }//if

  usb.println("Beginning PreFlight...");

  kxAccel.enableAccel();  //Start accelerometer reading

  digitalWrite(STATUS_LED_PIN, HIGH);

  prev_alt = altitudeFind(ms5611.getPressurePascal(), Po, To);
  prevTime = millis();
  vel = 0;   // reset filter

}//setup()

// ---   ---   ---   ---   ---   ---   ---   ---   ---   ---   ---   ---   ---   ---   ---   ---   ---   ---   ---

//      LOOP

// ---   ---   ---   ---   ---   ---   ---   ---   ---   ---   ---   ---   ---   ---   ---   ---   ---   ---   ---

void loop(){

  /*---------|----------*\
      |SENSOR READING|    
  \*---------|----------*/
  
  //read pressure/temp
  ms5611.read();     //Read the data from the ms5611, which gets stored in object

  //Get variables for pressure and temperature
  float P = ms5611.getPressurePascal();  // Pascals
  float T = ms5611.getTemperature() + 273.15; // Kelvin

  //Kalman Filtering on pressure
  float P_filter = kalmanFilter.updateEstimate(P);

  //Find Altitude from filtered Pressure
  // float alt = altitudeFind(P_filter,Po,To);

  float alt = altitudeFind(P_filter, Po, To);

  //read gyro
  mpu6050.getEvent(&a, &g, &temp);

  //read accelerometer
  kxAccel.getAccelData(&kxData);
  // kxAccel.offsetValues(kxData.xData, kxData.yData, kxData.zData);

  //--- CANBUS DATA SENDING
  if (millis() - lastSend >= CANBUS_DATAINT){
    //send Temperature, altitude, and Flight stage
    //sendCANtemp(T);
    usb.print("Pres(Pa): ");
    usb.print(P_filter, 2);
    usb.print(", Temp(K): ");
    usb.print(T);
    usb.print(", Alt(m): ");
    usb.println(alt);
    sendCANaltitude(alt);
    sendCANstage(STATE);
    lastSend = millis();
  }//if

  /*---\/---\/---\/---\/---*\
       |  STATE MACHINE |    
  \*---/\---/\---/\---/\---*/

  switch (STATE){
    case 0:   //Pre-Flight Stage  
      // Data logging
      if( millis() - lastLog >= PRE_DATAINT){
        logDataToFlash(P,P_filter,T,&a,&g,&kxData);
        lastLog = millis();
      }//if
      //Perform Launch Checks
      
      if(detectLaunch(alt)){
          STATE = 1;  
          digitalWrite(STATUS_LED_PIN,LOW);
      }//if
      break;
      
    case 1:   //Ascending
      //logging data 
      if( millis() - lastLog >= ASC_DATAINT){
        logDataToFlash(P,P_filter,T,&a,&g,&kxData);
        lastLog = millis();
      }//if
       
      //Perform Apogee check
      if(detectApogee(alt)){
        STATE = 3;
        digitalWrite(FIRE_DROGUE_PIN,HIGH);
        usb.println(F("FIRING DROGUE"));
      }//if
      
      //updating prevs
      prevTime = curTime;
      prev_alt = alt;
      break;

    case 3:   //Descending with drogue
      //logging data
      if( millis() - lastLog >= DROGUE_DATAINT){
        logDataToFlash(P,P_filter,T,&a,&g,&kxData);
        lastLog = millis();
      }//if

      //fire main parachute if necessary
      if(alt<= MAIN_DEPLOY_THRESHOLD){
        digitalWrite(FIRE_MAIN_PIN, HIGH);
        usb.println(F("FIRING MAIN"));
        STATE = 4;
        mainTimer = millis();
      }//if
      break;
      
    case 4:   //descending with main
      //logging data
      if(millis() - mainTimer <= 5000){
        if(millis() - lastLog >= MAIN_DATAINTFAST){
          logDataToFlash(P,P_filter,T,&a,&g,&kxData);
          lastLog = millis();
        }//if
      }//if
      else if(millis() - mainTimer > 5000){
        if(millis() - lastLog >= MAIN_DATAINTSLOW){
          logDataToFlash(P,P_filter,T,&a,&g,&kxData);
          lastLog = millis();
        }//if
      }//if
      
      //perform Landing check
      if(detectLand(alt)){
        landingTimer = millis();
        STATE = 5;
        usb.println("LANDED");
      }//if
      //updating prevs
      prevTime = curTime;
      prev_alt = alt;
      break;
      
    case 5:   // Landed
      //logging data
      if (millis() - landingTimer <= 1800000){
        if( millis() - lastLog >= LAND_DATAINT){
          logDataToFlash(P,P_filter,T,&a,&g,&kxData);
          lastLog = millis();

        }//if
      }
      //slower logging rate after 30 mins to save power
      else if (millis() - landingTimer > 1800000 && millis() - landingTimer < 3600000){
        if( millis() - lastLog >= LAND_SLOW_DATAINT){
          logDataToFlash(P,P_filter,T,&a,&g,&kxData);
          lastLog = millis();

        }//if
      }
      //power save mode after 60 mins
      else if (millis() - landingTimer > 36000000){
        
      }
      break;

  }//switch
}//loop()

/*---\/---\/---\/---\/---*\
     |  DATA LOGGING |    
\*---/\---/\---/\---/\---*/

void logDataToFlash( float pressure, float pressure_filter, float temp,sensors_event_t *a, sensors_event_t *g, outputData *kxData){
  uint32_t dataArr[11] = {0,0,0,0,0,0,0,0,0,0,0};

  dataArr[0] = millis();
  dataArr[1] = uint32_t(pressure);
  dataArr[2] = uint32_t(temp*1000);
  // accelleration data (from mpu or qma)
  // dataArr[4] = static_cast<uint32_t>(a->acceleration.x*1e6);
  // dataArr[5] = static_cast<uint32_t>(a->acceleration.y*1e6);
  dataArr[3] = flash.unsignify(a->acceleration.z*10000);
  
  dataArr[4] = flash.unsignify(kxData->xData*10000);
  dataArr[5] = flash.unsignify(kxData->yData*10000);
  dataArr[6] = flash.unsignify(kxData->zData*10000);

  //gyro data
  dataArr[7] = flash.unsignify(g->gyro.x*10000);
  dataArr[8] = flash.unsignify(g->gyro.y*10000);
  dataArr[9] = flash.unsignify(g->gyro.z*10000);

  // dataArr[7] = flash.unsignify(altitudeFind(pressure_filter, altimeterBasePres(500),altimeterBaseTemp(500)));

  //state
  dataArr[10] = STATE;

  //write to FLASH
  bool success = flash.writeRow(dataArr);
  if (success) {
    //usb.println("[MDE] Data logged successfully");
  } else {
      usb.println("[MDE] Flash write failed!");
  }

}//logDataToFlash()

/*---\/---\/---\/---\/---*\
     |  EVENT CHECKS |    
\*---/\---/\---/\---/\---*/
bool detectLaunch(float alt){
  if (strike >= 3) {
    
    if (!potentialLaunch) {
      //if first measurement, begin launch countdown
      potentialLaunch = 1;
      potentialLaunchStart = millis();
    } else {
      //if not first, check time since first
      if (millis() - potentialLaunchStart >= LAUNCH_GRACE){
        //THEN LAUNCH IS ON
        return true;
      }//if
    }//if
    
  } else {
    // 3 strike system. If detects altitude over the threshold three consecutive times, then launch detected:
    if (alt > LAUNCH_THRESHOLD) {
      strike += 1;
    } else {
      strike = 0;
    }
    potentialLaunch = 0;
  }//if
  return false;
}//end detectLaunch


bool detectApogee(float alt){
  curTime = millis();
  float dh = (alt - prev_alt)/(curTime-prevTime) * 1000;

  vel = 0.9*vel + 0.1*dh;
   
  if (vel < -0.1) {    //check if velocity is negative (with some error margin)
    if (!potentialApo) {
      //if first measurement, begin apogee countdown
      potentialApo = 1;
      potentialApoStart = millis();
    } else {
      //if not first, check time since first
      if (millis() - potentialApoStart >= APO_GRACE){
        //THEN WE HAVE HIT APOGEE
        return true;
      }//if
    }//if
    
  } else {
    potentialApo = 0;    
  }//if
  
  return false;    
}//detectApogee()

bool detectLand(float alt) {
  curTime = millis() ;
  float dh = (alt - prev_alt)/(curTime-prevTime) *1000;
  
  vel = 0.9*vel + 0.1*dh;
  
  if (vel <= LAND_THRESHOLD) {  //check if velocity is less than -0.5 [m/s]
    
    if (!potentialLand) {
      //if first measurement, begin Land countdown
      potentialLand = 1;
      potentialLandStart = millis();
      
    } else {
      //if not first, check time since first
      if (millis() - potentialLandStart >= LAND_GRACE){
        //THEN WE HAVE LANDED
        return true;      
      }//if
    }//if
  
  } else {
    potentialLand = 0;
  }//if

  return false;  
}//detectLand()

/*---\/---\/---\/---\/---*\
      |  DEBUG MENU |    
\*---/\---/\---/\---/\---*/

/*
 * Empties all bytes from incoming Serial buffer.
 * Used by Debug mode
 */
void emptySerialBuffer() {
  while (usb.available()) {usb.read();}
}//emptySerialBuffer()

/*
 * Called when Debug mode is activated;
 * all normal board functions will cease.
 * Only purpose is to respond to serial
 * commands.
 */
void debugMode() {

  // Status LED static "ON"
  digitalWrite(STATUS_LED_PIN, HIGH);

  while (true) {

    // Empty buffer
    emptySerialBuffer();

    // Wait for command
    while (!usb.available()) {}
    uint8_t cmd = usb.read();

    if (cmd == 'I') {
      // "Identify" command; return board name
      usb.println(F("[MDE] STINGER_ALT"));
    }//if
    if (cmd == 'F') {
      // "FlashInfo" command; return flash usage stats
      usb.print(F("[MDE] "));
      usb.print(flash.getMaxSize());
      usb.print(F(","));
      usb.println(flash.getCurSize());   
    }//if
    if (cmd == 'D') {
      // "DumpFlash" command; dump all flash contents via serial
      flash.beginDataDump(&usb);
    }//if
    if (cmd == 'L') {
      // LOG DATA
      //Get variables for pressure and temperature
      float P = ms5611.getPressurePascal(); //pascals
      float T = ms5611.getTemperature() + 273.15; // Kelvin
      float P_filter = kalmanFilter.updateEstimate(P);
      mpu6050.getEvent(&a, &g, &temp);
      logDataToFlash(P,P_filter,T,&a,&g,&kxData);
    }  
    if (cmd == 'E') {
      // "EraseFlash" command; completely erase contents of flash.
      // Should be restarted afterwards
      usb.println(F("[MDE] Erasing Flash"));
      SerialFlash.eraseAll();
      while (SerialFlash.ready() == false) {}
      //flash.init(&SerialFlash);
      usb.println(F("[MDE] Complete"));
    }//if
    if (cmd == 'Q') {
        // QUERY SENSORS
        // kxAccel.enableAccel();
          //Read pressure/temperature
        ms5611.read();
        usb.println("[MDE] --MS5611--");
        usb.print(F("[MDE] Temperature (1.00C): "));
        usb.println(ms5611.getTemperature() + 273.15);
        usb.print(F("[MDE] Pressure (Pa): "));
        usb.println(ms5611.getPressurePascal());

        //read gyro
      sensors_event_t a, g, temp;
      mpu6050.getEvent(&a, &g, &temp);
      usb.println("[MDE] --MPU6050--");
      usb.print("[MDE] X Rotation (rad/s): ");
      usb.println(g.gyro.x);
      usb.print("[MDE] Y Rotation (rad/s): ");
      usb.println(g.gyro.y);
      usb.print("[MDE] Z Rotation (rad/s): ");
      usb.println(g.gyro.z);
      
        //read accelerometer
      // outputData kxData;
      //kxAccel.getAccelData(&kxData);
      //kxAccel.offsetValues(kxData.xData, kxData.yData, kxData.zData);

      // usb.println("[MDE] --kxAccel--");
      // usb.print("[MDE] X Acceleration (g): ");
      // usb.println(kxData.xData);
      // usb.print("[MDE] Y Acceleration (g): ");
      // usb.println(kxData.yData);
      // usb.print("[MDE] Z Acceleration (g): ");
      // usb.println(kxData.zData);   
    }//if

  }//while

}//debugMode()

/*
 * Updates the status LED; should be run in loop() 
 */
void handleStatusFlash() {
  if (millis() - lastFlash > flashDelay) {
    lastFlash = millis();
    // toggle LED
    digitalWrite(STATUS_LED_PIN, !digitalRead(STATUS_LED_PIN));
  }//if
}//handleStatusFlash()

/*---\/---\/---\/---\/---*\
    | ALTIMETER FUNC |    
\*---/\---/\---/\---/\---*/
float altitudeFind(float P, float Po, float To){
  float alt = (To/LAPSE_RATE)*( pow(P/Po,0.19026627) - 1 );
  return alt;
}//altitudeFind()

/*
 * Finding Po and To
 */
float altimeterBaseTemp(int sample){
  float sum = 0;

  for (int i=0 ; i<sample ; i++){
    ms5611.read();
    float Ti = ms5611.getTemperature() + 273.15; // Kelvin
    sum +=Ti;
  }//for
  float To = sum/sample;

  return To;
}//altimeterBaseTemp()

float altimeterBasePres(int sample){
  float sum = 0;
  
  for (int i=0 ; i<sample ; i++){
    ms5611.read();
    float Pi = ms5611.getPressurePascal(); //pascals
    sum +=Pi;
  }//for
  float Po = sum/sample;

  return Po;
}//altimeterBasePres()

/*---\/---\/---\/---\/---*\
    | CANBUS FUNCTIONS |    
\*---/\---/\---/\---/\---*/

/*
 * Sends current altitude over CANBUS
 */
void sendCANaltitude(float alt){

  //Adjust altitude into uin32_t 
  //pushes decimals to first 8 bits
  int32_t altint = (alt);
  
  //Start shifting bits (b0 = LSB)
  uint8_t b0 = altint & 0xFF;
  uint8_t b1 = altint>>8 & 0xFF;
  uint8_t b2 = altint>>16 & 0xFF;
  uint8_t b3 = altint>>24 & 0xFF;
  
  //Build the CANBUS message
  CAN_TX_msg.id = (ALTIMETER_MOD_CANID+ALTITUDE_CANID);
  CAN_TX_msg.len = 4;
  
  CAN_TX_msg.buf[0] = b0;
  CAN_TX_msg.buf[1] = b1 ;
  CAN_TX_msg.buf[2] = b2 ;
  CAN_TX_msg.buf[3] = b3 ;
  
  canb.write(CAN_TX_msg);     //send
}//sendCANaltitude()

/*
 * Sends the current STAGE over the CANBUS
 */
void sendCANstage(int stage){
  //Build the CANBUS message
  CAN_TX_msg.id = (ALTIMETER_MOD_CANID+FLIGHT_STAGE_CANID);
  CAN_TX_msg.len = 1;
  
  CAN_TX_msg.buf[0] = (stage)&0xFF;
  
  canb.write(CAN_TX_msg);     //send
}//sendCANstage()
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

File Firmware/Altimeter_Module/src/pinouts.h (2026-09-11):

#ifndef PINOUTS_H
#define PINOUTS_H

#include <Arduino.h> // needed for PB/A# pin assignment
#include <cstdint>

// pinouts.h - STINGER Altimeter Module V2.0 Pin Mapping (STM32F103CB)
// Reference: STINGER V2.0 Hardware KiCad Schematic & PCB Layout (av-recovery/Schematics)
namespace pins {

// --- Serial (USB-UART Bridge; TX/RX are swapped on the PCB) ---
//  !!! Fix in next board spin !!!
//  Use software serial
constexpr uint8_t kSerialTx = PA9;  // USART_TX -> USB_RX
constexpr uint8_t kSerialRx = PA10; // USART_RX <- USB_TX

// --- CAN ---
constexpr uint8_t kCanRx = PB8;
constexpr uint8_t kCanTx = PB9;

// --- Flash (SPI) ---
constexpr uint8_t kFlashReset = PA11;
constexpr uint8_t kFlashCs    = PB12;
constexpr uint8_t kSpiSclk    = PB13;
constexpr uint8_t kSpiMiso    = PB14;
constexpr uint8_t kSpiMosi    = PB15;

// --- Sensor I2C (barometer + IMUs) ---
constexpr uint8_t kI2cScl     = PB10;
constexpr uint8_t kI2cSda     = PB11;
constexpr uint8_t kMs5611Addr  = 0x76;   // barometer
constexpr uint8_t kMpu6050Addr = 0x69;   // IMU
constexpr uint8_t kKx134Addr   = 0x1F;   // accelerometer

// --- IMU interrupts ---
constexpr uint8_t kAccelInt1 = PB5;
constexpr uint8_t kAccelInt2 = PB6;
constexpr uint8_t kGyroInt   = PB7;

// --- Recovery (pyro fire + continuity) ---
constexpr uint8_t kFireDrogue = PA1;
constexpr uint8_t kContDrogue = PA2;
constexpr uint8_t kFireMain   = PA3;
constexpr uint8_t kContMain   = PA4;

// --- Power sensing ---
constexpr uint8_t kBattSense = PB0;
constexpr uint8_t kCurrSense = PB1;

// --- Buzzer (TIM1 complementary PWM pair) ---
constexpr uint8_t kBuzzerB = PA7;
constexpr uint8_t kBuzzerA = PA8;

// --- LEDs ---
constexpr uint8_t kRgbData  = PB3;   // JTAG pin, requires JTAG disable/remap
constexpr uint8_t kDebugLed = PA15;  // JTAG pin, requires JTAG disable/remap

}

#endif // PINOUTS_H

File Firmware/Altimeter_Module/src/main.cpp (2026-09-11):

#include "node.h"

#include <IWatchdog.h>
#include <logger.h>
#include <SoftwareSerial.h>
#include <SPI.h>

#include <aim_file_system.h>
#include <aim_flight_recorder.h>
#ifndef FLIGHT_BUILD
#include <aim_console.h>
#endif

static constexpr uint32_t kWatchdogTimeoutUs  = 10000000U; // 10 seconds timeout
static constexpr uint8_t  kMaxRxFramesPerLoop = 8U;

static AimCanHardware g_canHw(node::kCanBaud, CAN1);
static AimNetwork g_aim(&g_canHw, node::kSource);
static SoftwareSerial g_serial(pins::kSerialRx, pins::kSerialTx);
static Logger g_log(g_serial, static_cast<uint8_t>(node::kSource), LogLevel::INFO);

static SPIClass g_flashSpi(pins::kSpiMosi, pins::kSpiMiso, pins::kSpiSclk);
static SpiNorFlashDriver g_flashDriver(pins::kFlashCs, g_flashSpi);
static AimFileSystem g_fs(&g_flashDriver);
static AimFlightRecorder g_recorder(g_fs, kLogCols, kLogOriginRefresh, kLogMaxSize, kLogHeaders);

static void serviceCanRx(void) {
  const uint32_t nowMs = millis();
  for (uint8_t i = 0U; i < kMaxRxFramesPerLoop; i++) {
    aim::Msg m = {};
    if (!g_aim.receive(m)) break;
    nodeOnRx(m, nowMs);
  }
}

#ifndef FLIGHT_BUILD
static void hookStatus(Stream& out) {
  out.print("name=");
  out.print(node::kName);
  out.print(" logMask=0x");
  out.print(static_cast<unsigned>(g_log.filterMask()), HEX);
  out.print(" syncedMs=");
  out.print(static_cast<unsigned long>(g_aim.syncedMillis()));
  out.print(" version=");
  out.print(aim::kNetworkVersionString);
  out.print(" schema=");
  out.print(static_cast<unsigned>(aim::kSchemaVersion));
  out.print(" build=");
  out.print(__DATE__);
  out.print(" ");
  out.println(__TIME__);
}
#endif  // FLIGHT_BUILD

void setup(void) {
  g_serial.begin(node::kSerialBaud);
  g_logger = &g_log;
  g_log.setFilterMask(static_cast<uint8_t>(LogLevel::INFO));  // INFO only
  LOG_INFO("Boot %s source=%u", node::kName, static_cast<unsigned>(node::kSource));

  SPI.begin();

  if (!g_aim.begin(aim::classBit(aim::Class::Time) |
                   aim::classBit(aim::Class::Event) |
                   aim::classBit(aim::Class::Heartbeat))) {
    LOG_ERROR("CAN init failed");
  }

  pinMode(pins::kFlashCs, OUTPUT);
  digitalWrite(pins::kFlashCs, HIGH);

  if (!g_fs.begin()) {
    LOG_WARN("Filesystem mount failed");
  } else if (!g_recorder.begin()) {
    LOG_WARN("Recorder init failed");
  } else {
    LOG_INFO("Flash ready");
  }

#ifndef FLIGHT_BUILD
  uint8_t nodeHookCount = 0U;
  const AimConsoleHook* nodeHooks = nodeConsoleHooks(nodeHookCount);

  static AimConsoleHook combinedHooks[8];
  uint8_t totalHooks = 0;
  combinedHooks[totalHooks++] = {'s', "status", hookStatus};
  for (uint8_t i = 0; i < nodeHookCount && totalHooks < 8; i++) {
    combinedHooks[totalHooks++] = nodeHooks[i];
  }
  aimConsoleInit(g_serial, g_fs, g_recorder, node::kName, combinedHooks, totalHooks);
#endif

  nodeInit();

  IWatchdog.begin(kWatchdogTimeoutUs);
  IWatchdog.reload();
  LOG_INFO("Watchdog ready (%lus timeout)", static_cast<unsigned long>(kWatchdogTimeoutUs / 1000000U));

#ifndef FLIGHT_BUILD
  g_serial.println("Console ready. d=enter debug");
#endif
}

void loop(void) {
  IWatchdog.reload();
  const uint32_t nowMs = millis();
  serviceCanRx();
  nodeUpdate(nowMs);
  if (!aimConsoleIsActive()) {
    nodeServiceLog(nowMs, g_recorder);
  }
  nodeServiceCanTx(nowMs, g_aim);
  g_aim.service(nowMs, nodeCurrentState(), nodeErrorBits());
#ifndef FLIGHT_BUILD
  aimConsoleService();
#endif
  IWatchdog.reload();
}

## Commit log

2026-04-01 prepare for dedicated av-recovery repo (GPS & Altimter only)
    [10018784-10210TLF.step, 10118194-0001LF-USB.step, 8890445_SWD_PINS.stp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]
2026-04-18 Add pre-release AimNetwork V0.3.1 for GPS Module Rev2.0
    - missing debug mode and flash writes!
    - keep old firmware for reference, delete soon
    [GPS_Module.ino, main.cpp]
2026-04-22 Fixed TODO, Added Strike System for Detect Launch
    detectLaunch() now checks for a change in altitude > LAUNCH_THRESHOLD (default=100 meters). Must detect a change for at least three cycles in a row to ensure launch has actually occured.
    [Altimeter_Module.ino]
2026-04-22 Changed Temperature to Kelvin
    Formulas required temperature to be in Kelvin but it was given as Celsius, so I changed it at every ms5611.getTemperature() location, and changed where it printed the units as Celsius (C), not Kelvin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
2026-04-24 Added readable time to GPS print
2026-06-14 fw(av-recovery): migrate GPS and Altimeter modules to AIM Network v0.6.x
    GPS Module: drops bespoke console.cpp/h in favour of shared aim_console
    library; rewrites main.cpp and node.* to v0.6.x API (aim::Source, aim::Msg,
    AimFileSystem, AimFlightRecorder); adds pinouts.h following workspace
    convention; removes stale Firmware/av-libraries submodule (pinned to v0.4.x).
    Altimeter Module: archives old monolithic .ino firmware to
    Altimeter_Module_old/ for future reference; establishes new v0.6.x scaffold
    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
    [Register_mapping.xlsx, test.csv]
2026-06-14 refactor(nodes): add nodeOnRx as standard 4th interface function
    Adds nodeOnRx(const aim::Msg&, uint32_t nowMs) to GPS and Altimeter nodes.
    serviceCanRx in main.cpp now delegates per-frame dispatch to nodeOnRx instead
    of doing it inline — making the drain loop identical boilerplate across all nodes.
    Both nodeOnRx bodies are stubs pending cross-node event subjects being defined.
    Also makes serviceCanRx static in both main.cpp files.
2026-06-15 av-recovery: migrate GPS_Module to node.* convention (schema v2)
    Slim main.cpp to wiring; move GPS logic + debug-snapshot console hooks
    into node.{cpp,h}. Build against schema-v2 av-libraries; platformio and
    README updates for GPS and Altimeter.
2026-06-18 Altimeter/GPS: pass nowMs into service()
    Match the updated AimNetwork::service(nowMs, state, errorBits) signature.
    [main.cpp]
2026-06-21 Altimeter/GPS: full node convention migration, baro + IMU bring-up
    Migrate Altimeter to node.h/node.cpp convention with console, LED status,
    and MS5611 barometer + LSM6DSO32 IMU initialization. Refactor GPS node
    to use aim::Job scheduling and lowerCamelCase naming throughout.
2026-07-22 refactor(gps): optimize GPS_Module telemetry, fix I2C stream bug, add 3D Flash logging & phase-adaptive rates
    [main.cpp, node.cpp]
2026-07-23 feat(altimeter): modernize node layout, add KX134 high-g driver, and enable 400kHz I2C
2026-07-23 feat(gps): update baud rate to 1Mbps, add SAM-M10Q 10Hz/High-G mode notes, and add TelemetryMode event handling
2026-07-23 docs(gps): emphasize mandatory u-center pre-flight check for SAM-M10Q 10Hz/High-G mode
2026-08-18 fix(recovery): fixed-rate jobs (Altimeter 100 Hz, GPS 10 Hz), watchdog 10 s armed after init
    Pre-launch 2026-08-19 build against av-libraries single-rate Job.
    [main.cpp, node.cpp]
2026-08-19 chore(recovery): pad build — INFO-only logging on Altimeter and GPS
